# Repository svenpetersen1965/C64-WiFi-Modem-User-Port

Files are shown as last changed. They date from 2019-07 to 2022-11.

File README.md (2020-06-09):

# C64-WiFi-Modem-User-Port
A NodeMCU (ESP8266) based WiFi modem for the C64's user port
This is a Wifi-Modem for the Commodore C64 Uperport, which is based on the ESP8266 (NodeMCU v3). It contains level shifters to 
translate between the NodeMCU 3.3V level and the User Port 5V level. This prevents stressing the User Port due to a level mismatch.

Further on, status LEDs and (in Rev. 1) a Reset switch is contained.

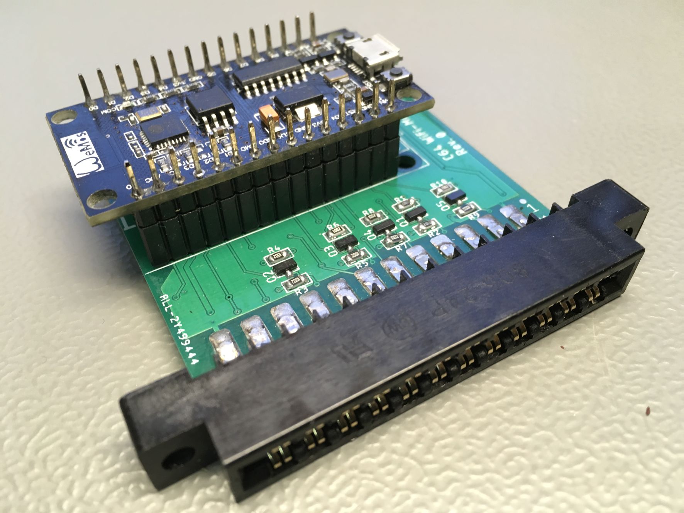
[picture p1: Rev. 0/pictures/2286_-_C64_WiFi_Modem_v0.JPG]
C64 Wifi modem


About the NodeMCU v3: There is a version, which is wider. The version that work is WeMOS NodeMCU v3, which is about 25.4mm wide. You can compare it to this picture, please. The right one has the labeling of the pins parallel to the edge of the PCB. 

The wiring follows the instruction on https://1200baud.wordpress.com/2017/03/04/build-your-own-9600-baud-c64-wifi-modem-for-20/ 

The firmware, required for the NodeMCU, can be obtained from the same website. Please follow the setup procedure described there.

Now, the STL files for a 3D printed case are available for this project.

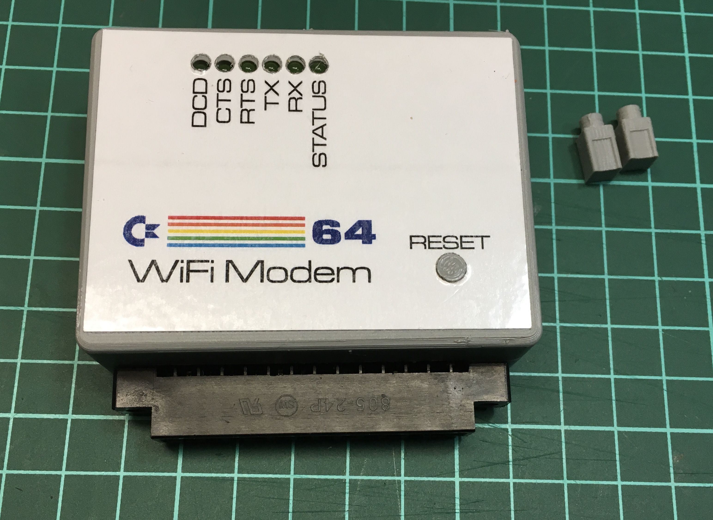
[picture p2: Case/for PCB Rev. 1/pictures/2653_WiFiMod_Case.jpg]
C64 Wifi modem (case)


There are three types of reset switch plungers for some common tact switch heights (4.3mm, 5mm and 7mm).

Rev. 1 works well, but only accepts the (smaller) WeMos NodeMCU v3 (approximately 48mx25mm). There is a bigger version available from the common sales platforms, which are bigger: 31mm x 57mm and don't fit the footprint of Rev. 1. This led to Rev. 2, which is now tested and working completely. 

Both sizes of the NodeMCU

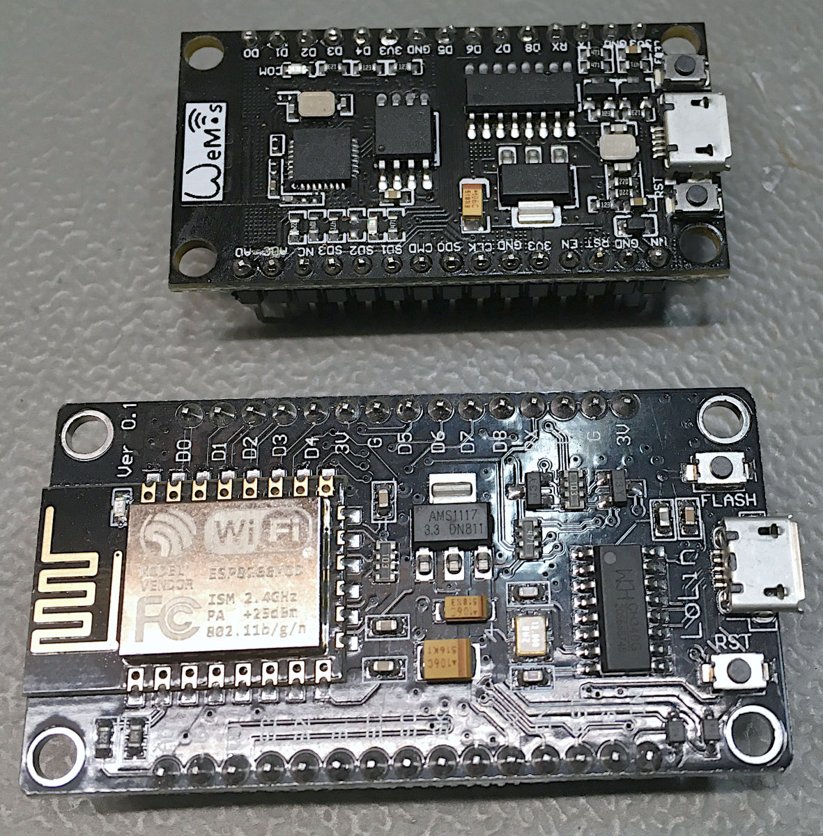
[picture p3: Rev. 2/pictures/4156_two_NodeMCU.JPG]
both sizes of NodeMCU


WiFi Modem Rev. 2 in case

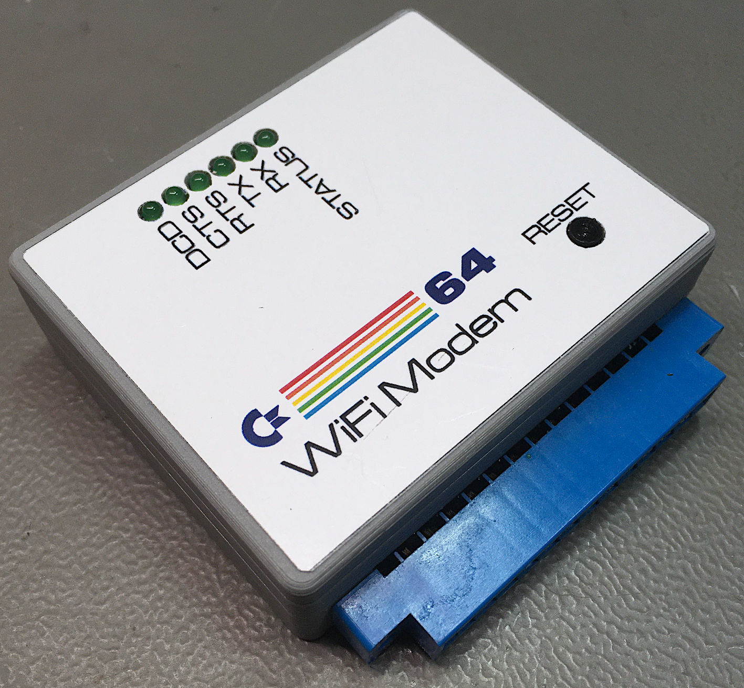
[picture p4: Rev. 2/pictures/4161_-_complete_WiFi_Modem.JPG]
C64 Wifi modem (case)


A nice blog about this project can be found here: <a href="https://medium.com/@gozdnijezek/c64-wifi-modem-user-port-by-sven-petersen-commodore-wifi-modem-21ab0eed411d">GozdniJezek: C64-WiFi-Modem-User-Port by Sven Petersen (Commodore WiFi modem)</a>

# Recommended Screws
For the case, I have used 2.9mm x 9.5mm (self taping) screws for sheet metal (C 2,9x9,5H, DIN 7981). 

# Calculation of the Component prices
The prices of the components was summed up. The total costs without the 3D printed case and any shipping fees is 16.19€ (May 2020). This might differ, depending on the source of the parts the Node MCU v3 can be obtained from non-domestic sources for less.

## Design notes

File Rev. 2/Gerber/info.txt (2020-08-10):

      
       Board: C64_Wifi_UserP
       Rev.:  2
  
       Files:
       ======
  
       All Gerber files are generated in extended gerber format (RS274X)
       *.TOP        : Film top copper
       *.BOT        :  -"- bottom copper
       *.STC        :  -"- top soldermask 
       *.STS        :  -"- bottom soldermask
       *.CRC        :  -"- cream top
       *.PLC        :  -"- silk screen top
       *.PLS        :  -"- silk screen bottom
       *.DK         : Drills plated Through (Excellon)
       *.NDK        : Drills not plated Through (Excellon)
       *.OUT        : Board outline
       
       Board Size:
       ===========
       Length     :   59.0 mm
       Width      :   53.3 mm
       Thickness  :   1.6 mm
       Material   :   FR 4
       Copper     :   35 um
       Surface    :   HASL
       
       Remarks:
       ========
       Width:    >=6mil
       Distance: >=6mil
       Drill:    >=0.35mm

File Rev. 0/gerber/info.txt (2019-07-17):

      
       Board: C64_Wifi_UserP
       Rev.:  0
  
       Files:
       ======
  
       All Gerber files are generated in extended gerber format (RS274X)
       *.TOP        : Film top copper
       *.BOT        :  -"- bottom copper
       *.STC        :  -"- top soldermask 
       *.STS        :  -"- bottom soldermask
       *.PLC        :  -"- silk screen top
       *.DK         : Drills plated Through (Excellon)
       *.NDK        : Drills not plated Through (Excellon)
       *.OUT        : Board outline

       Board Size:
       ===========
       Length     :   54.0 mm
       Width      :   53.3 mm
       Thickness  :   1.6 mm
       Material   :   FR 4
       Copper     :   35 um
       Surface    :   HASL
       
       Remarks:
       ========

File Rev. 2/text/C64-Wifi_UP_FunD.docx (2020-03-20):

C64 WiFi-Modem for User Port Rev. 2

Functional Description

J1 is connecting to the C64 user port. The logic levels are TTL (5V)-levels. The NodeMCU v3 (M1) contains all functionality, WiFi included. Its signal level is 3.3V, so level shifters are required. Those are implemented in the MOSFETs (Q1 – Q5).

The modem signals are active low. The inverters (IC1) are used to drive LEDs. The RxD and TxD lines might toggle often. To obtain a good LED brightness, the output of the inverters IC1D and IC1E are buffered in a capacitor, which is charged via a diode and discharged via the base resistor and the base of a transistor, which is then driving an LED.

The last LED (LD6) is driven by the signal EXLED from the NodeMCU. It serves as a status LED for the NodeMCU software. According to the comments in the software, a LOW on this output should switch the Status-LED on, thus the inverter IC1F is required.

J2 is a spare SPI bus connection. The functionality is not implemented in the software, the pin header may stay not populated.

SW1 serves as a RESET switch for the C64. It is a standard 6mm tact switch.

A LOW level on the C64’s signal pulls the NodeMCU’s LOW via the Schottky diode D3. This way, the NodeMCU is reset together with the C64.

C64-Wifi_UP_FunD.docx 05.02.2020 11:49 Drafted by Sven Petersen Page 2 of 2 Doc.-No.: 000-6-00-00

C64-Wifi_UP_FunD.docx 05.02.2020 11:49 Drafted by Sven Petersen Page 1 of 1 Doc.-No.: 120-6-01-02

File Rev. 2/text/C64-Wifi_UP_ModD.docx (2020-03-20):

C64 WiFi-Modem for User Port Rev. 2

Module Description

This board is a WiFi modem for the User Port of the Commodore C64. It is based on the project “Build your own 9600 Baud C64 WiFi Modem For $10” of “1200BAUD” (https://1200baud.wordpress.com/2017/03/04/build-your-own-9600-baud-c64-wifi-modem-for-20/).

The WiFi functionality is implemented in the NODEMCU V3 development board/module, which contains an Espressive ESP8266, a WiFi and RISC processor. This module can be programmed with free software via a micro USB cable.

The board contains status and activity LEDs and connects to the User Port of the Commodore C64.

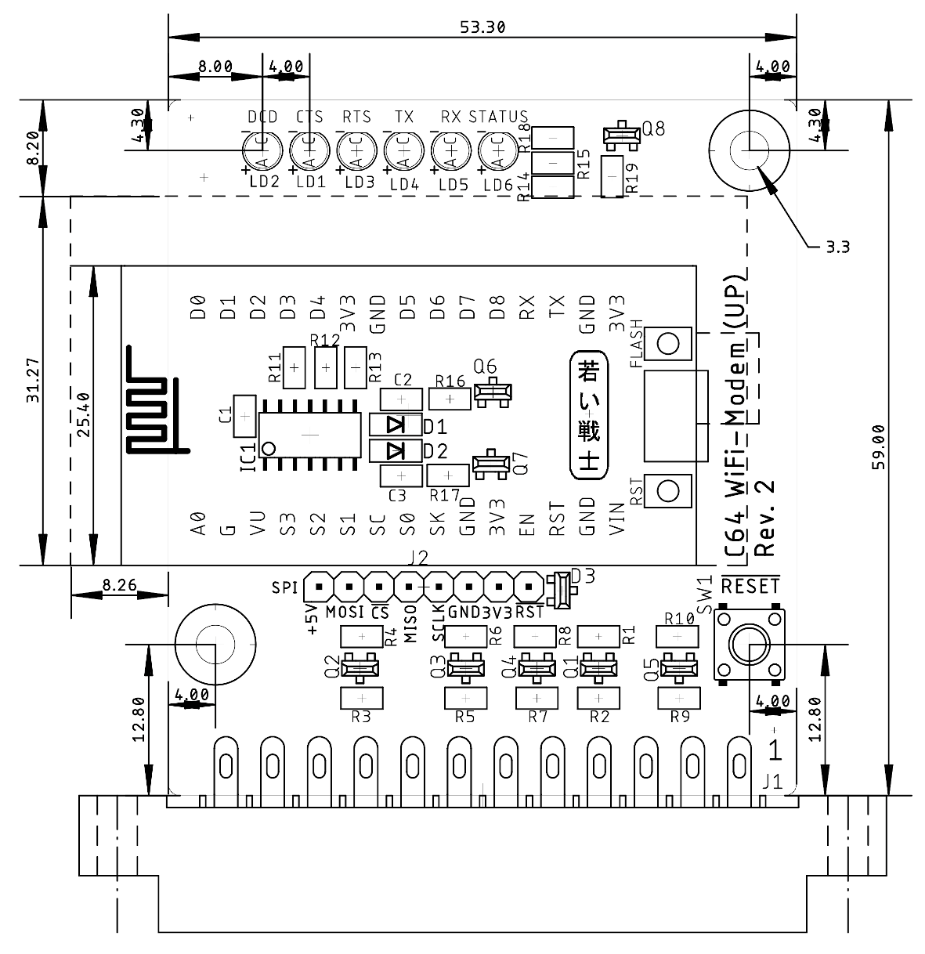
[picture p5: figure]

Figure 1: Dimensions of the WiFi modem board

For the NodeMCU V3 programming and the required C64 software, refer to the article mentioned before.

The board contains level shifters, that translate between the NodeMCU 3.3V level and the User Port 5V level. According to the data sheet, the ESP8266 is not 5V-level tolerant. Its protection diodes might limit the HIGH level to below 4V. Without the level shifters, the User Port/6526 CIA might be stressed by the HIGH level being pulled to this level.


Figure 2: The narrow and the wide NodeMCU

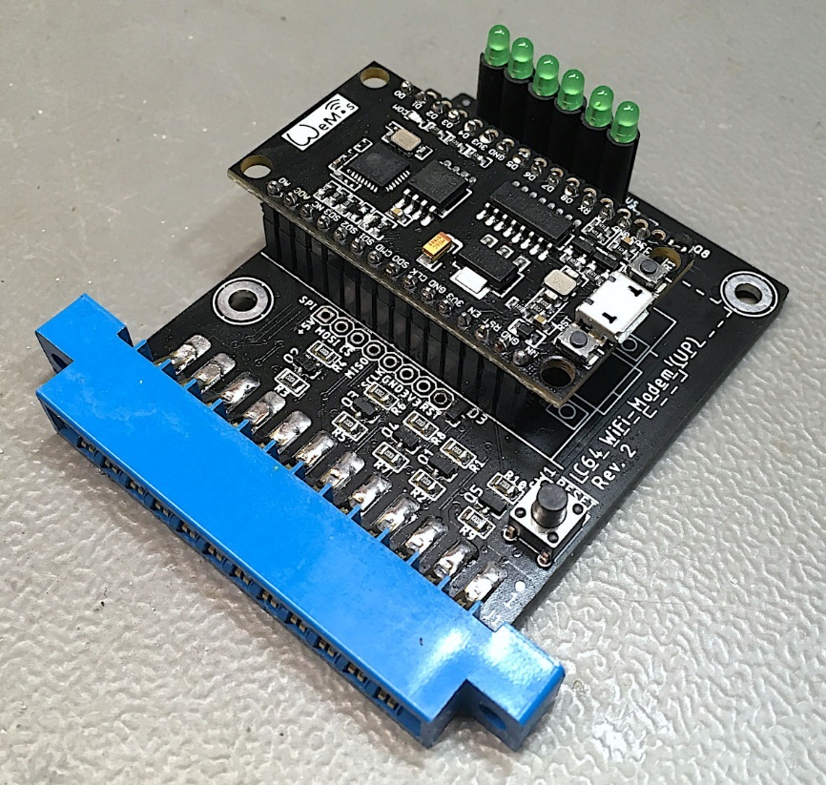
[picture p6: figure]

Figure 3: WiFi Modem with narrow NodeMCU v3

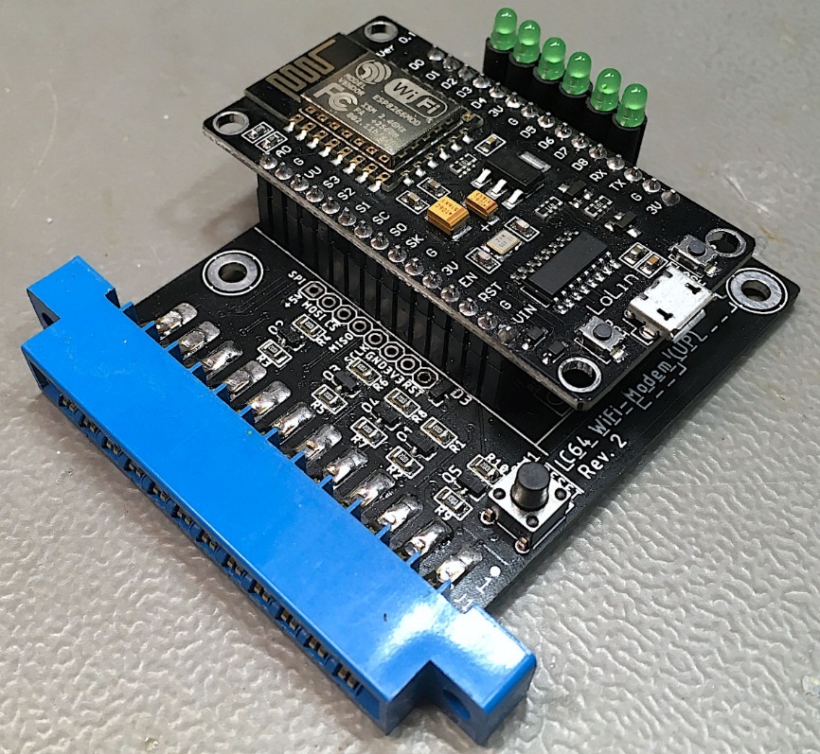
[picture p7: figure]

Figure 4: WiFi modem with the wide NodeMCU

# Logic connections

3.3V level | | | 5V level
Pin | NodeMCU V3 | Signal | User Port | Pin
29 | GPIO5 (D1) | RTS | PB1 | D
28 | GPIO4 (D2) | CTS | PB6 | K
26 | GPIO2 (D4) | DCD | PB4 | H
22 | GPIO12 (D6) | Status-LED | - | -
19 | RXD0 (RX) | RXD | PA2, SP1 | M, 5
18 | TXD0 (TX) | TXD | /FLAG2, PB0, SP2 | B, C, 7
- | - | | PB7, CNT2 | L, 6

# Connectors

## User Port

2 x 12 edge connector, pitch 3.96mm

Pin | Signal | Pin | Signal
1 | GND | A | GBD
2 | +5V | B, C | TXD
3 | | D | RTS
5 | RXD | H | DCD
6 | CNT2 | K | CTS
7 | TXD | L | CNT2
12 | GND | M | RXD
| | N | GND

## SPI (spare)

8p. pin header, pitch 2.54mm. The function of the SPI-Bus is not implemented in the NodeMCU software. The signals have a 3.3V level. 3.3V, 5V and GND are connected to this pin header.

Pin | Signal
1 | +5V
2 | MOSI
3
4 | MISO
5 | SCLK
6 | GND
7 | +3.3V
8 | (Reset Signal NodeMCU)

# Revision History

## Rev. 0

Prototype, functional. Labeling of the LEDs was not perfect, the Status LED was inverted.

## Rev. 0 → Rev. 1

- Board Revision
- LEDs changed to 3mm standard LEDs
- The “WiFi” LED is now named “Status” and it is inverted
- The Labeling from RX and TX was swapped, since before it was labeled from the perspective of the NodeMCU
- Positions of LEDs have moved
- A pin header for a spare SPI-Bus connection is added
- Two mounting holes for a not yet designed enclosure are added
- A -Button is added
- The C64 Reset affects the NodeMCU

## Rev. 1 → Rev. 2

- Board Revision
- The original WeMos NodeMCU footprint and the wider footprint of other vendors both fit the PCB
- The case Rev. 2 is required

C64-Wifi_UP_ModD.docx 20.03.2020 19:02 Drafted by Sven Petersen Page 2 of 2 Doc.-No.: 120-6-01-02

C64-Wifi_UP_ModD.docx 20.03.2020 19:02 Drafted by Sven Petersen Page 1 of 1 Doc.-No.: 120-6-01-01

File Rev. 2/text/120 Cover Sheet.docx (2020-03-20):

Project Documentation

C64 WiFi-Modem for User Port

Project number: 120

Revision: 2

Date: 05.02.2020

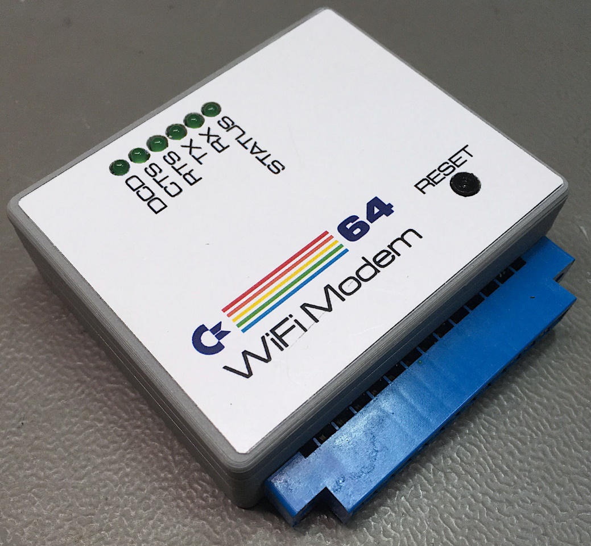
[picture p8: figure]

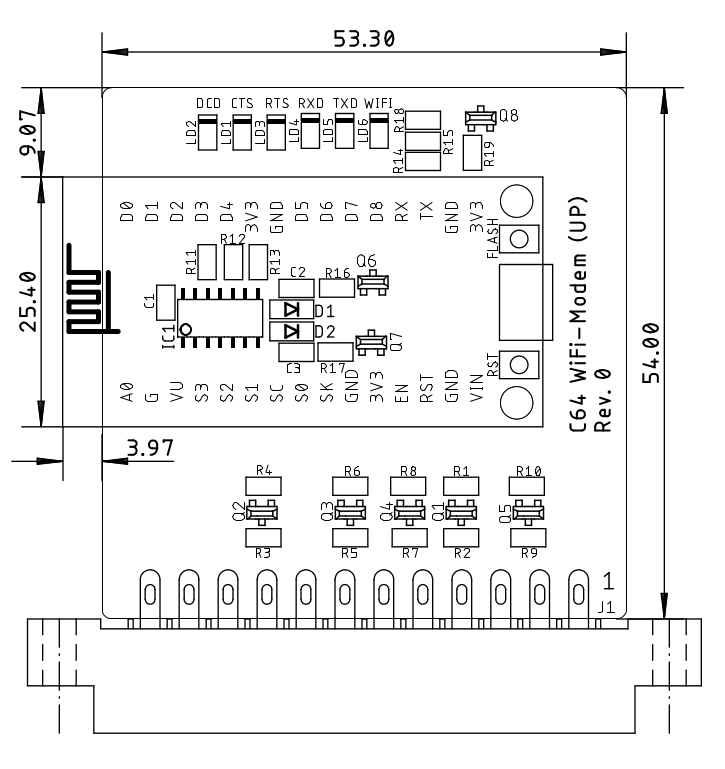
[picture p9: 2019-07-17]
Rev. 0/pictures/C64_WiFi_UP.png

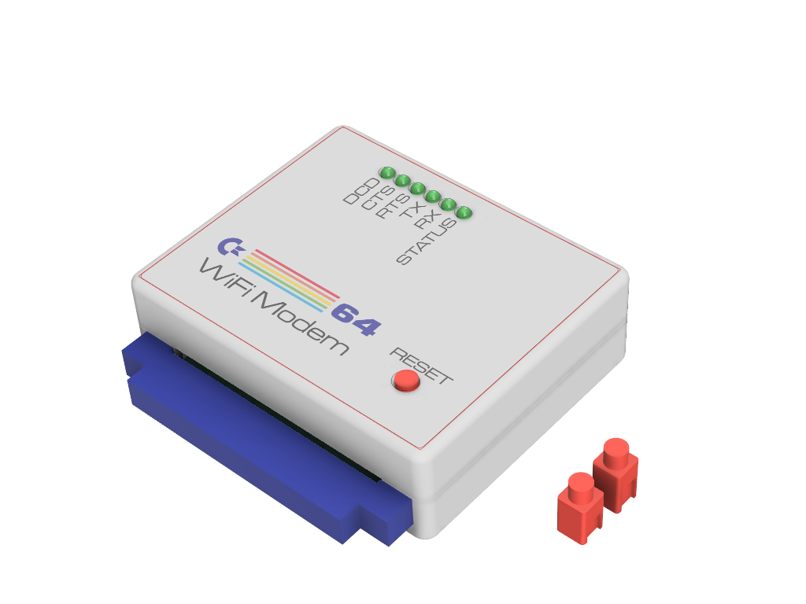
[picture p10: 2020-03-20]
Case/for PCB Rev. 2/pictures/C64-WiFi_UP_PCB2 v7.png

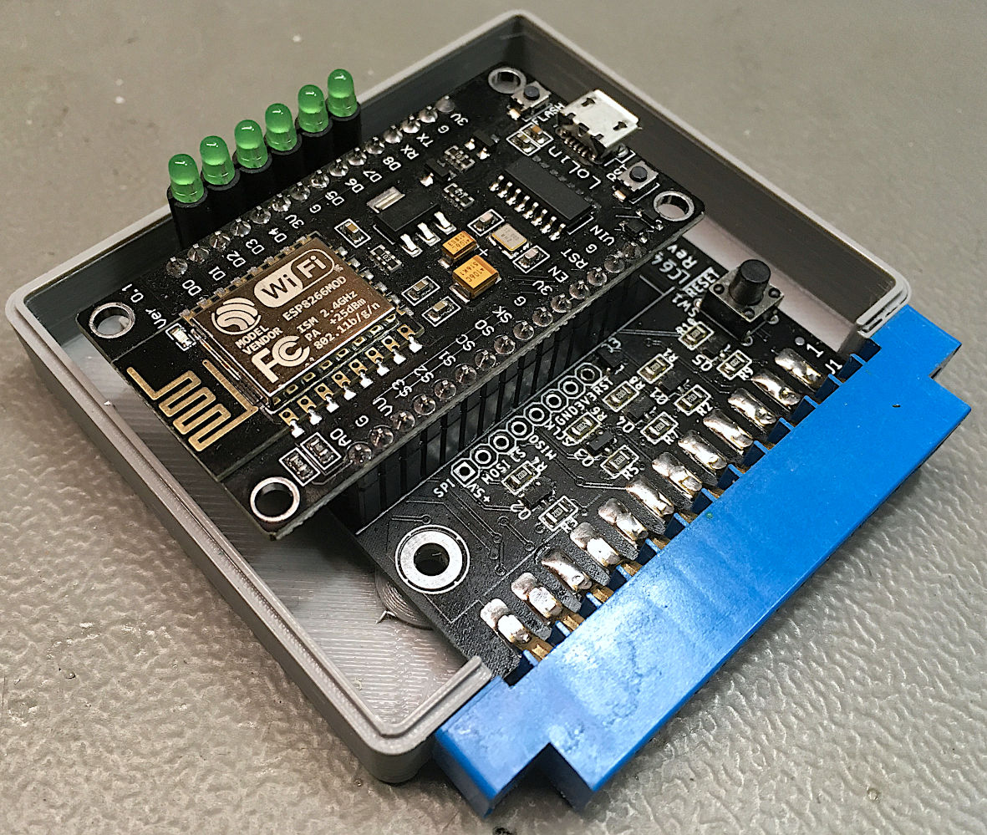
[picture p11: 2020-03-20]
Rev. 2/pictures/4159_-_in_bottom_shell.JPG

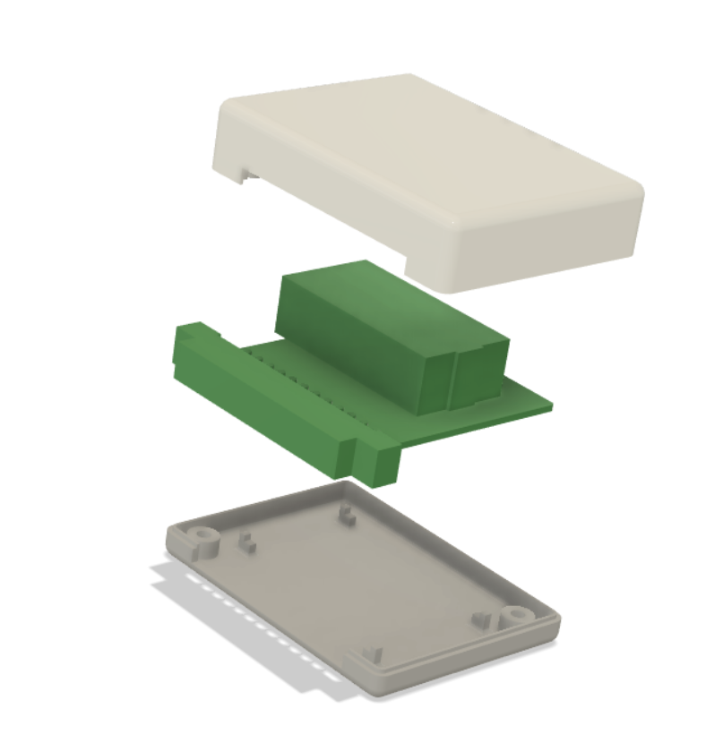
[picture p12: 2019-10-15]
Case/for PCB Rev. 0/pictures/C64-Wifi_UP_PCB0_explosion.png

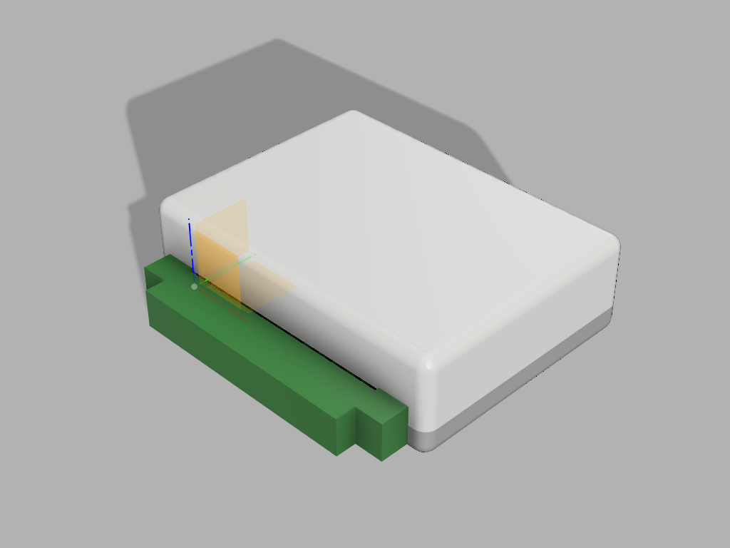
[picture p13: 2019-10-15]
Case/for PCB Rev. 0/pictures/C64-Wifi_UP_PCB0 v5.png

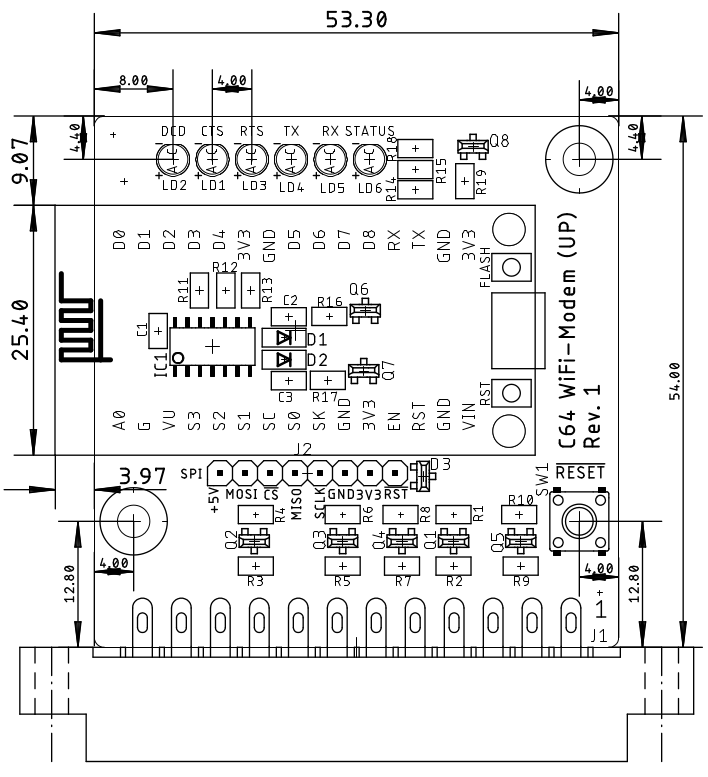
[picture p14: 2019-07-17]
Rev. 1/pictures/C64_WiFi_UP.png

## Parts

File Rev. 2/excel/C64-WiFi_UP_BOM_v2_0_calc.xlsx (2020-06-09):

C64 WiFi-Modem for User Port Rev. 2
Bill of Material Rev. 2.0
Pos. | Qty | Value | €/each | € | Comment
1 | 1 | 120-2-01-01 | 1.00 € | 1.00 € | 2 layer, Cu 35µ, HASL, 54.0 x 53.3, 1.6mm FR4
2 | 6 | 3mm/gn | 0.07 € | 0.42 € | Standard 3mm green LEDs
3 | 3 | 100n | 0.05 € | 0.15 € | ceramic cap, 0805, 25V or better
4 | 13 | 10k | 0.03 € | 0.39 € | chip resistor, 0805, 5% or better
5 | 6 | 330R | 0.03 € | 0.18 € | chip resistor, 0805, 5% or better
6 | 1 | 74HC14D | 0.20 € | 0.20 € | ST micro, NXP, TI etc. e.g. Reichelt SMD HC 14
7 | 3 | BC846B | 0.02 € | 0.06 € | SMD NPN transistor, e.g. Reichelt BC 846B NXP
8 | 5 | BSS138 | 0.04 € | 0.20 € | SMD MOSFET, e.g. Reichelt BSS 138 SMD
9 | 1 | 2x12, 3.96mm pitch | 3.00 € | 3.00 € | edge connector for C64 user port, ebay or online shops
10 | 2 | LL4148 | 0.02 € | 0.04 € | diode SMD, e.g. Reichelt LL4148
11 | 1 | NodeMCU V3 | 8.40 € | 8.40 € | e.g. WeMOS NodeMCU v3. ebay or online shops or Reichelt DEBO JT ESP8266, either the origial narror footprint or the 31.1mm wide footprint of other vendors.
12 | 2 | socket strip 15p. 2.54mm pitch | 0.99 € | 1.98 € | e.g. MPE Garry 115-1-015, Reichelt MPE 115-1-015
13 | 1 | 8p, 2.54mm pin header | 0.00 € | 0.00 € | not populated
14 | 1 | BAT54 | 0.02 € | 0.02 € | schottky diode
15 | 1 | JTP-1130 | 0.15 € | 0.15 € | Namea Electronics. Or standard 6x6mm tact switch
16 |  |  | Total | 16.19 €

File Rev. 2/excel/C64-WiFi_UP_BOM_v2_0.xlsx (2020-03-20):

C64 WiFi-Modem for User Port Rev. 2
Bill of Material Rev. 2.0
Pos. | Qty | Value | Footprint | Ref.-No. | Comment
1 | 1 | 120-2-01-01 | 2 Layer | PCB Rev. 1 | 2 layer, Cu 35µ, HASL, 54.0 x 53.3, 1.6mm FR4
2 | 6 | 3mm/gn | 3mm LED | LD1, LD2, LD3, LD4, LD5, LD6 | Standard 3mm green LEDs
3 | 3 | 100n | 0805 | C1, C2, C3 | ceramic cap, 0805, 25V or better
4 | 13 | 10k | 0805 | R1, R2, R3, R4, R5, R6, R7, R8, R9, R10, R16, R17, R19 | chip resistor, 0805, 5% or better
5 | 6 | 330R | 0805 | R11, R12, R13, R14, R15, R18 | chip resistor, 0805, 5% or better
6 | 1 | 74HC14D | SO-14 | IC1 | ST micro, NXP, TI etc. e.g. Reichelt SMD HC 14
7 | 3 | BC846B | SOT23 | Q6, Q7, Q8 | SMD NPN transistor, e.g. Reichelt BC 846B NXP
8 | 5 | BSS138 | SOT23 | Q1, Q2, Q3, Q4, Q5 | SMD MOSFET, e.g. Reichelt BSS 138 SMD
9 | 1 | 2x12, 3.96mm pitch | USERPORT | J1 | edge connector for C64 user port, ebay or online shops
10 | 2 | LL4148 | SOD80C | D1, D2 | diode SMD, e.g. Reichelt LL4148
11 | 1 | NodeMCU V3 | NODEMCUV3 | M1 | e.g. WeMOS NodeMCU v3. ebay or online shops or Reichelt DEBO JT ESP8266, either the origial narror footprint or the 31.1mm wide footprint of other vendors.
12 | 2 | socket strip 15p. 2.54mm pitch |  | (M1) | e.g. MPE Garry 115-1-015, Reichelt MPE 115-1-015
13 | 1 | 8p, 2.54mm pin header |  | J2 | not populated
14 | 1 | BAT54 | SOT23 | D3 | schottky diode
15 | 1 | JTP-1130 | 6mm tact switch | SW1 | Namea Electronics. Or standard 6x6mm tact switch
 |  | Rev. 0 -> Rev. 1
Pos. | 1 | Board Revision
Pos. | 2 | changed to 3mm led
Pos. | 13 | new
Pos. | 14 | new
Pos. | 15 | new
 |  | Rev. 1 -> 2
Pos. | 1 | Board Revision

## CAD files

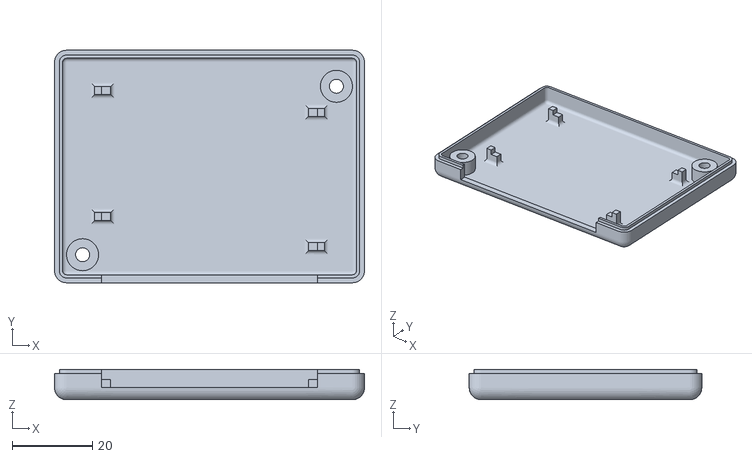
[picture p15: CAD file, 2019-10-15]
Case/for PCB Rev. 0/stl/bottom shell.stl
77.3 x 58.0 x 7.60

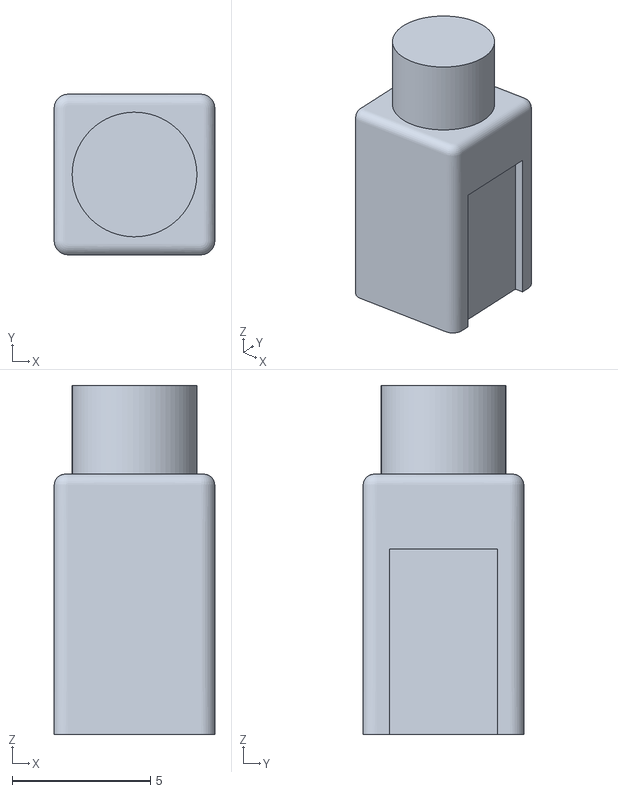
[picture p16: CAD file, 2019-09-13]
Case/for PCB Rev. 1/STL/Plunger (4.3mm).stl
5.80 x 5.80 x 12.6

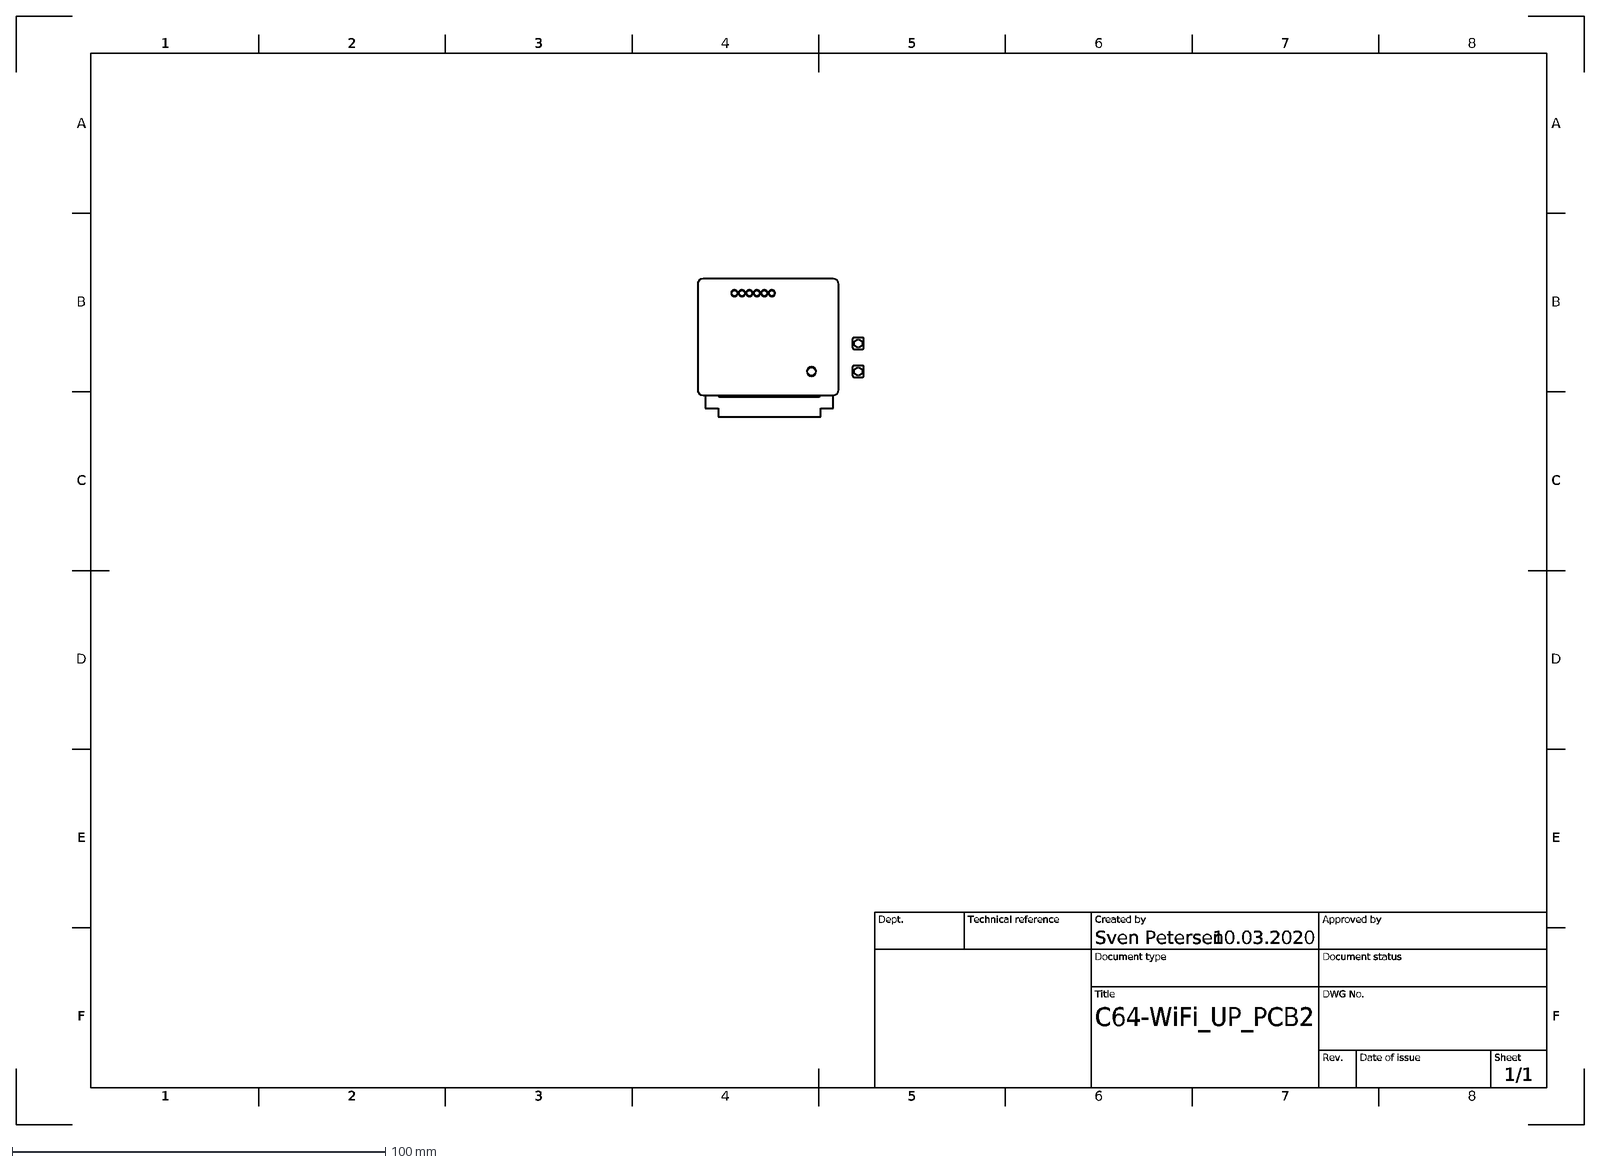
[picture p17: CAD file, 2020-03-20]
Case/for PCB Rev. 2/label/dxf/Untitled Sheet1.dxf
1
A
2
3
4
5
6
7
8
B
C
D
E
F
10.03.2020
1/1
C64-WiFi_UP_PCB2
Sven Petersen
Dept.
Technical reference
Created by
Approved by
Document type
Document status
Title
DWG No.
Rev.
Date of issue
Sheet

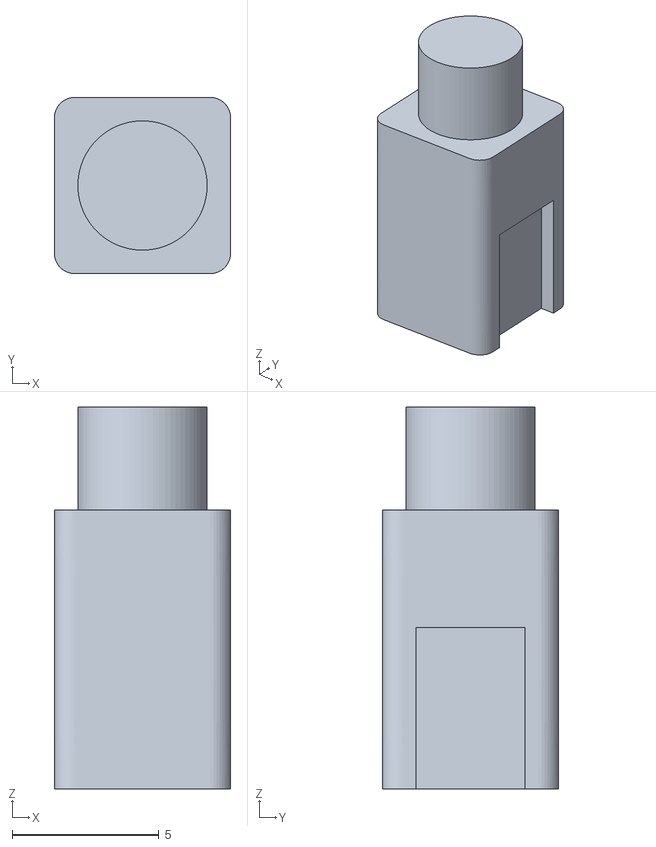
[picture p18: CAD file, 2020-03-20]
Case/for PCB Rev. 2/stl/plunger_4mm.stl
6.00 x 6.00 x 13.0

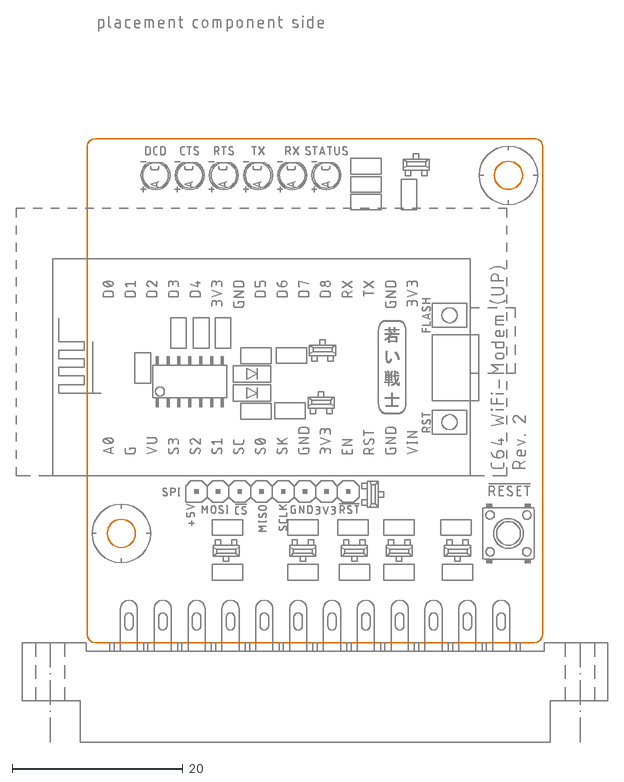
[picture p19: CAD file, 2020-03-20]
Rev. 2/dxf/C64-Wifi_UserP.dxf
69.2 x 84.9

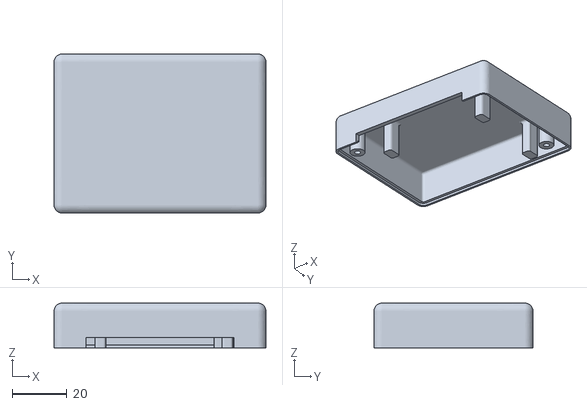
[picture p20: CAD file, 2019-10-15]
Case/for PCB Rev. 0/stl/Top shell.stl
77.3 x 58.0 x 16.4

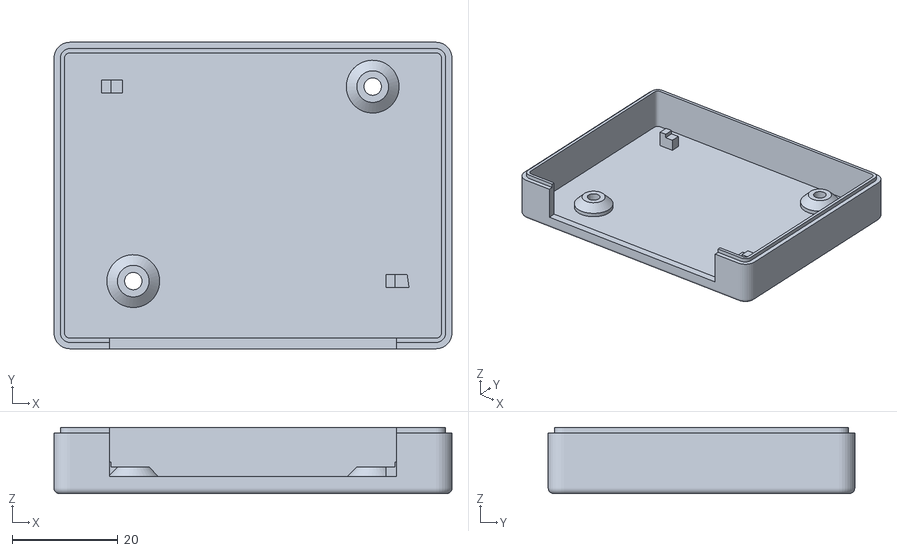
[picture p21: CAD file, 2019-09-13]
Case/for PCB Rev. 1/STL/bottom shell.stl
75.3 x 58.0 x 12.5

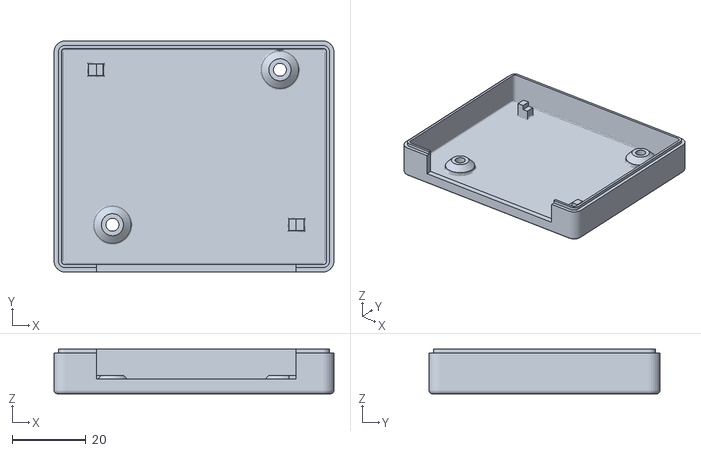
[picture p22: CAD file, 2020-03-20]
Case/for PCB Rev. 2/stl/C64_Wifi2_bottom.stl
75.7 x 62.5 x 12.1

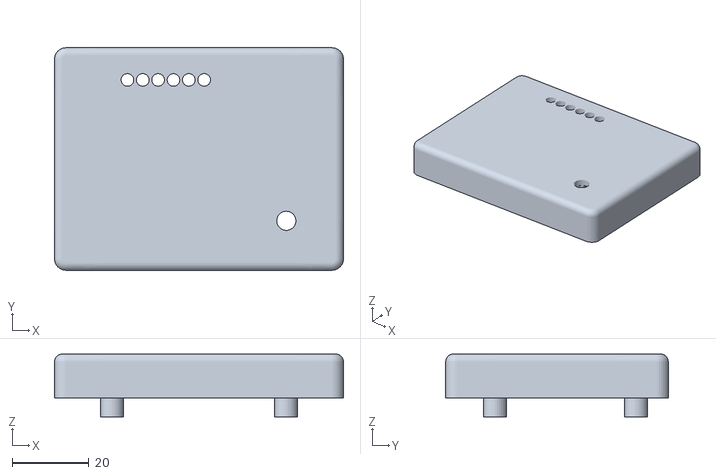
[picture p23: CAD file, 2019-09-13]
Case/for PCB Rev. 1/STL/Top shell.stl
75.3 x 58.0 x 16.4

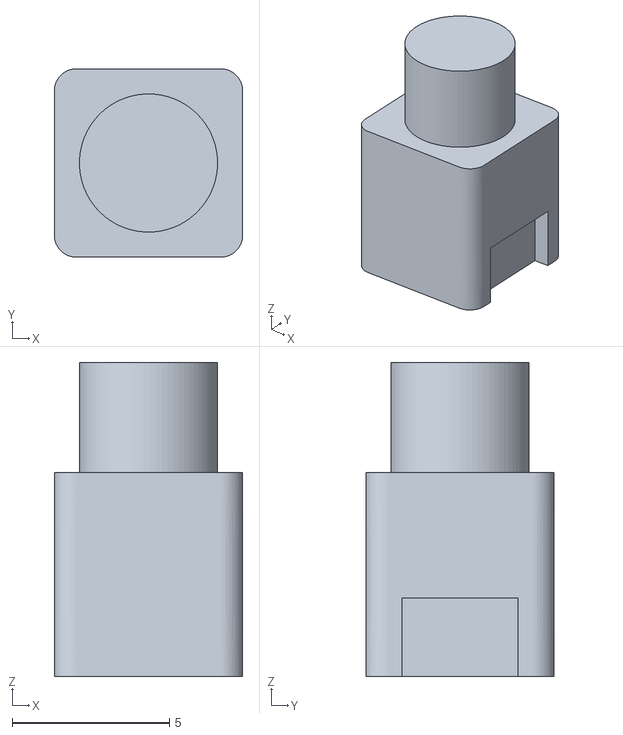
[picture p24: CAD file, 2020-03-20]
Case/for PCB Rev. 2/stl/plunger_7mm.stl
6.00 x 6.00 x 10.0

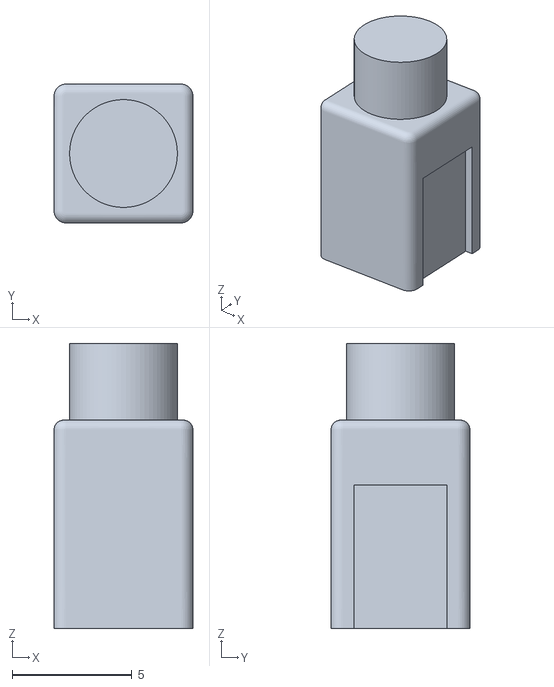
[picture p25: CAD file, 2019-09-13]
Case/for PCB Rev. 1/STL/Plunger (5mm).stl
5.80 x 5.80 x 11.9

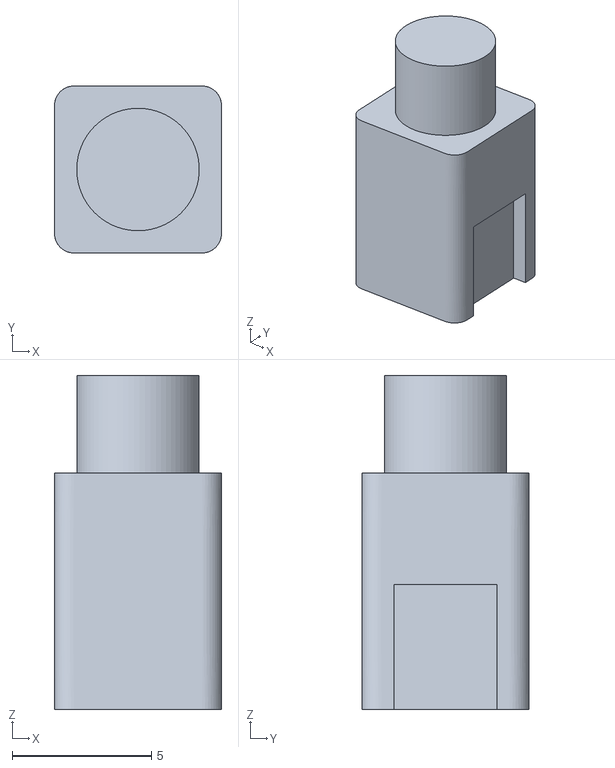
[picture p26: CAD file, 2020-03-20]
Case/for PCB Rev. 2/stl/plunger_5mm.stl
6.00 x 6.00 x 12.0

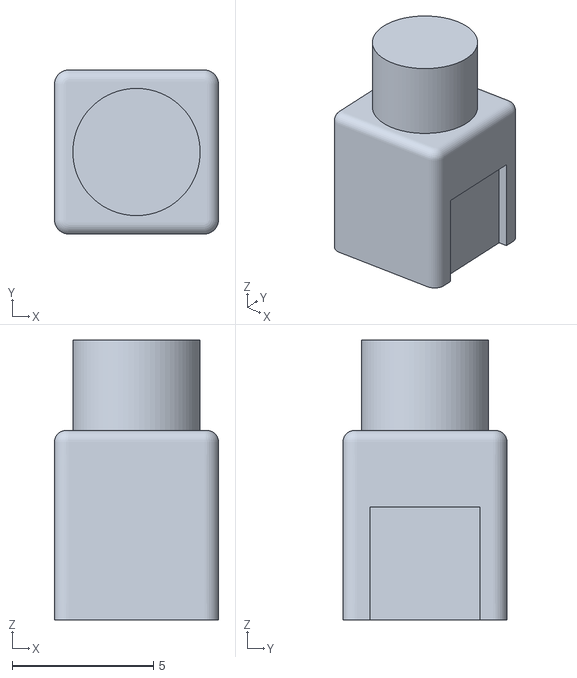
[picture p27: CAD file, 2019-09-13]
Case/for PCB Rev. 1/STL/Plunger (7mm).stl
5.80 x 5.80 x 9.90

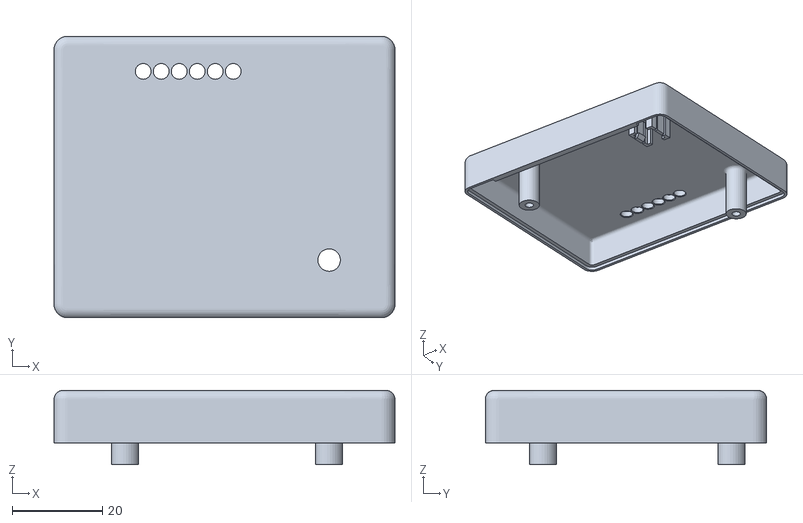
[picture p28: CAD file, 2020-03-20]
Case/for PCB Rev. 2/stl/C64_WiFi2_Top.stl
75.7 x 62.5 x 16.5

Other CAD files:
Case/for PCB Rev. 0/fusion 360/C64-Wifi_UP_PCB0 v6.f3d
Case/for PCB Rev. 1/Fusion 360/C64-Wifi_UserP v34.f3d
Case/for PCB Rev. 2/Fusion 360/C64-WiFi_UP_PCB2 v9.f3d

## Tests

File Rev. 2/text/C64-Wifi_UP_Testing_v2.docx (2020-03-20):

C64 WIFI Modem (User Port) Rev. 2

Testing v2

# Setup

The C64 WiFi Modem (Rev. 1) is driven by a C64 (Mainboard: ASSY250469 with ARMSID), which also connects to an Ultimate II+.

# Current consumption

The current is measured with a Fluke 89 IV multimeter, which is connected between the power supply and the Power jack of the C64.

First the maximum current of the C64 setup mentioned before is determined without the DUT being connected to the user port. CCGMS 2017 v6 was loaded from the Ultimate II+.

The measured result IMAX is 998.7mA.

In the next step, the DUT was connected and the measurement was repeated. This time, the result is 1095.5mA.

The current consumption of the Modem board might vary depending on the operations/state. It can eb assumed, that is it approximately 100mA.

# Connection Test

With the CCGMS software, the Modem was set up, three different WiFi connections were established:

- An iPad Pro acting as an access point
- A WAP (wireless access point)
- A Router

The connections to the WiFi networks could be established, repeatedly. The WAP did not connect anymore after a few days. Since the WAP was far away and all other connections continued working, it was assumed, that either the settings or the distance of the WAP were causing the problem.

After setting up the dialer with several BBS connections and Port numbers, the WiFi-Modem and CCGMS software could connect to those BBSes and exchange data and hold the connection in a stable behavior.

# Conclusion

The functionality of Rev. 0 is given, the labeling of the LEDs needs to be changed. The Status LED needs to be inverted. Refer to document 120-6-03-00: Testing Rev. 0.

Rev. 1 was built and tested. The LEDs cab be viewed properly, their behavior is ok. The reset button resets both, the C64 and the modem. The modem does not reset the C64. The designed 3D printed case (for PCB Rev. 1) fits well. The modem connects to WiFi and is able to dial in a variety of BBSes.

Rev. 2 was built and tested. The designed 3D printed case (for PCB Rev. 2) fits well. The tests were conducted with both, the narrow NodeMCU and the wide NodeMCU. The modem connects to WiFi and is able to dial in a variety of BBSes.

C64-Wifi_UP_Testing_v2.docx 20.03.2020 19:12 Drafted by Sven Petersen Page 2 of 2 Doc.-No.: 120-6-03-02

C64-Wifi_UP_Testing_v2.docx 20.03.2020 19:12 Drafted by Sven Petersen Page 1 of 1 Doc.-No.: 120-6-03-01.1

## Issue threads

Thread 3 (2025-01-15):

Do we need a specific height female pin header?

kennyevo, 2025-01-15:
I’ve assembled a rev2 board with the exact same nodemcu that’s in the readme, but the rev2 top case doesn’t sit on the pcb, the nodemcu sits too high.
What height should the socket headers be?

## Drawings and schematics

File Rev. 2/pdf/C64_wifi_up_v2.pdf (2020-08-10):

# Project Documentation

## C64 WiFi-Modem for User Port

## Project number: 120

## Revision: 2

## Date: 05.02.2020

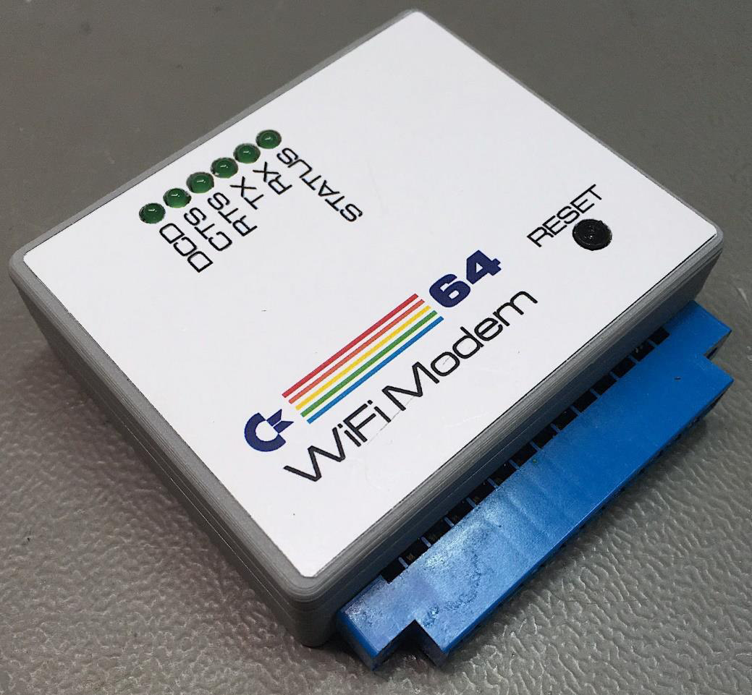
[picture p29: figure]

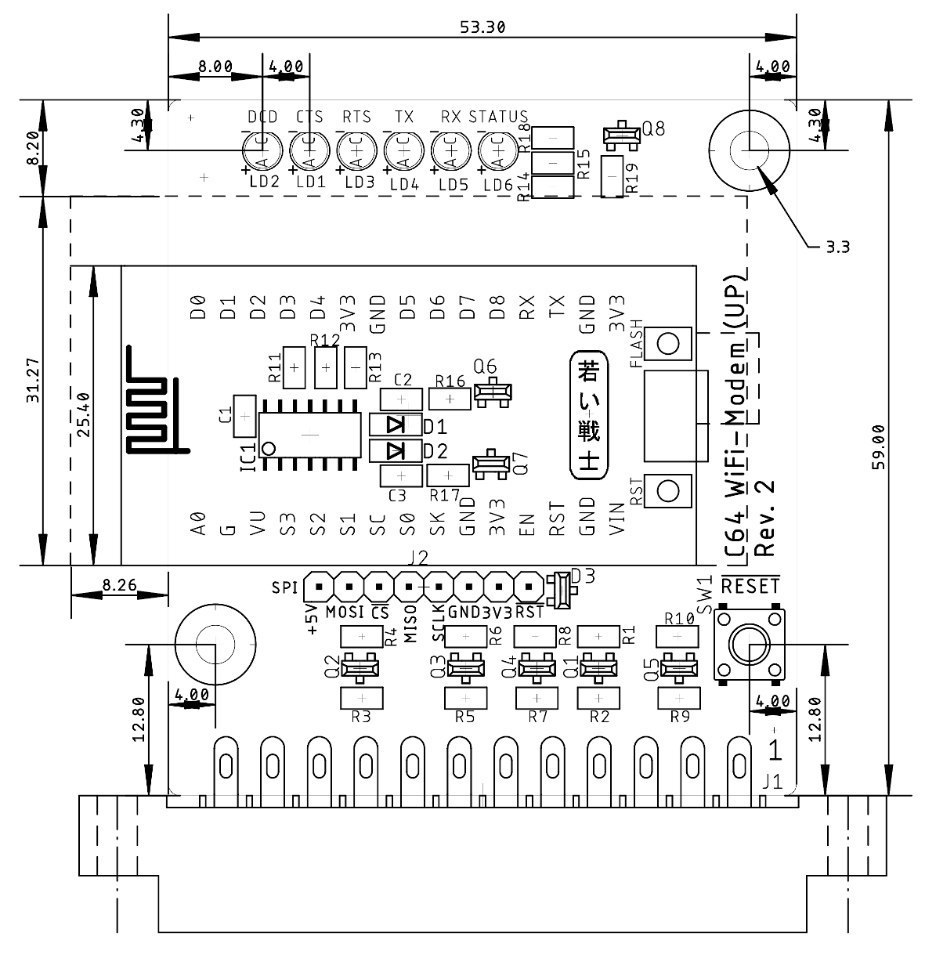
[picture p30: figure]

C64-Wifi_UP_ModD.docx | | 20.03.2020 19:02
Drafted by Sven Petersen | Page 1 of 4 | Doc.-No.: 120-6-01-02

### C64 WiFi-Modem for User Port Rev. 2

### Module Description

This board is a WiFi modem for the User Port of the Commodore C64. It is based on the project “Build your own 9600 Baud C64 WiFi Modem For $10” of “1200BAUD” (https://1200baud.wordpress.com/2017/03/04/build-your-own-9600-baud-c64-wifi-modem-for-20/). (https://1200baud.wordpress.com/2017/03/04/build-your-own-9600-baud-c64-wifi-modem-for-20/)

The WiFi functionality is implemented in the NODEMCU V3 development board/module, which contains an Espressive ESP8266, a WiFi and RISC processor. This module can be programmed with free software via a micro USB cable.

The board contains status and activity LEDs and connects to the User Port of the Commodore C64.

Figure 1: Dimensions of the WiFi modem board

For the NodeMCU V3 programming and the required C64 software, refer to the article mentioned before.

The board contains level shifters, that translate between the NodeMCU 3.3V level and the User Port 5V level. According to the data sheet, the ESP8266 is not 5V-level tolerant. Its protection diodes might limit the HIGH level to below 4V. Without the level shifters, the User Port/6526 CIA might be stressed by the HIGH level being pulled to this level.

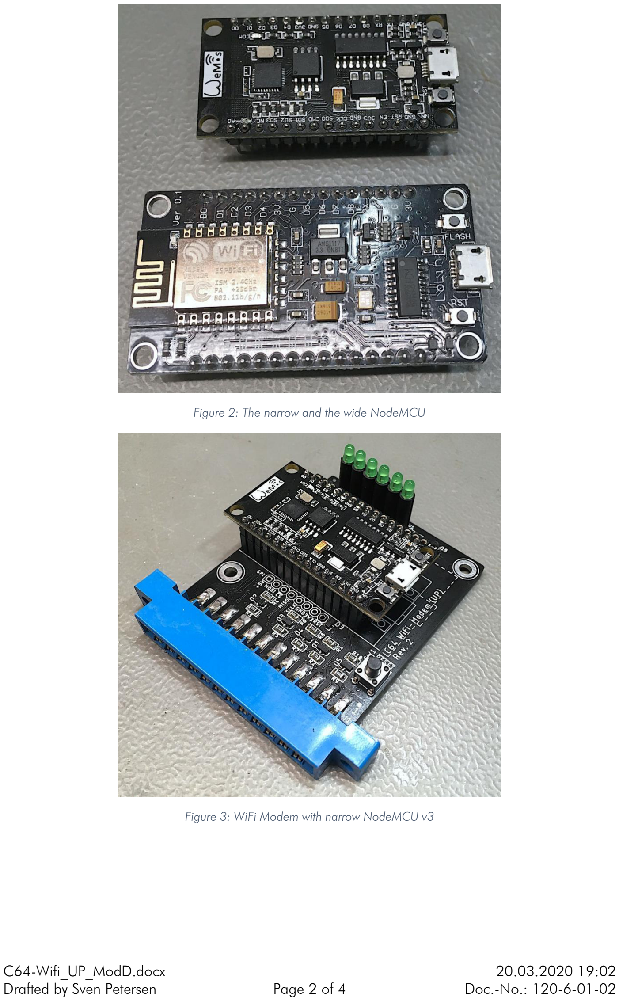
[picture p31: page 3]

C64-Wifi_UP_ModD.docx | | 20.03.2020 19:02
Drafted by Sven Petersen | Page 2 of 4 | Doc.-No.: 120-6-01-02

Figure 2: The narrow and the wide NodeMCU

Figure 3: WiFi Modem with narrow NodeMCU v3

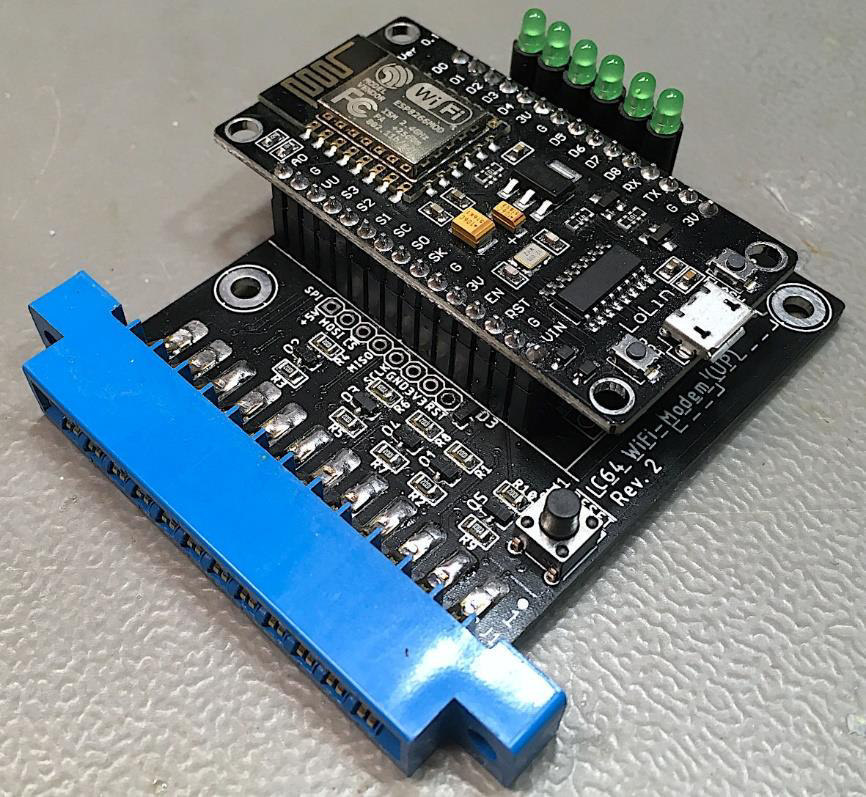
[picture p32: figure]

C64-Wifi_UP_ModD.docx | | 20.03.2020 19:02
Drafted by Sven Petersen | Page 3 of 4 | Doc.-No.: 120-6-01-02

Figure 4: WiFi modem with the wide NodeMCU

## Logic connections

| 3.3V level | | | 5V level
Pin | NodeMCU V3 | Signal | User Port | Pin
29 | GPIO5 (D1) | RTS | PB1 | D
28 | GPIO4 (D2) | CTS | PB6 | K
26 | GPIO2 (D4) | DCD | PB4 | H
22 | GPIO12 (D6) | Status-LED | - | -
19 | RXD0 (RX) | RXD | PA2, SP1 | M, 5
18 | TXD0 (TX) | TXD | /FLAG2, PB0, SP2 | B, C, 7
- | - | | PB7, CNT2 | L, 6

## Connectors

### User Port

### 2 x 12 edge connector, pitch 3.96mm

Pin Signal | Pin Signal
1 | GND | A | GBD
2 | +5V | B, C | TXD
3 | RESET | D | RTS
5 | RXD | H | DCD
6 | CNT2 | K | CTS
7 | TXD | L | CNT2
12 | GND | M | RXD
| | N GND

C64-Wifi_UP_ModD.docx | | 20.03.2020 19:02
Drafted by Sven Petersen | Page 4 of 4 | Doc.-No.: 120-6-01-02

### SPI (spare)

8p. pin header, pitch 2.54mm. The function of the SPI-Bus is not implemented in the NodeMCU software. The signals have a 3.3V level. 3.3V, 5V and GND are connected to this pin header.

Pin Signal
1 +5V
2 MOSI
3 CS

4 MISO
5 SCLK
6 GND
7 +3.3V
8 RST (Reset Signal NodeMCU)

## Revision History

### Rev. 0

Prototype, functional. Labeling of the LEDs was not perfect, the Status LED was inverted.

### Rev. 0 → Rev. 1

- Board Revision
- LEDs changed to 3mm standard LEDs

### - The “WiFi” LED is now named “Status” and it is inverted

- The Labeling from RX and TX was swapped, since before it was labeled from the perspective of the NodeMCU
- Positions of LEDs have moved
- A pin header for a spare SPI-Bus connection is added
- Two mounting holes for a not yet designed enclosure are added
- A RESET -Button is added
- The C64 Reset affects the NodeMCU

### Rev. 1 → Rev. 2

- Board Revision
- The original WeMos NodeMCU footprint and the wider footprint of other vendors both fit the PCB
- The case Rev. 2 is required

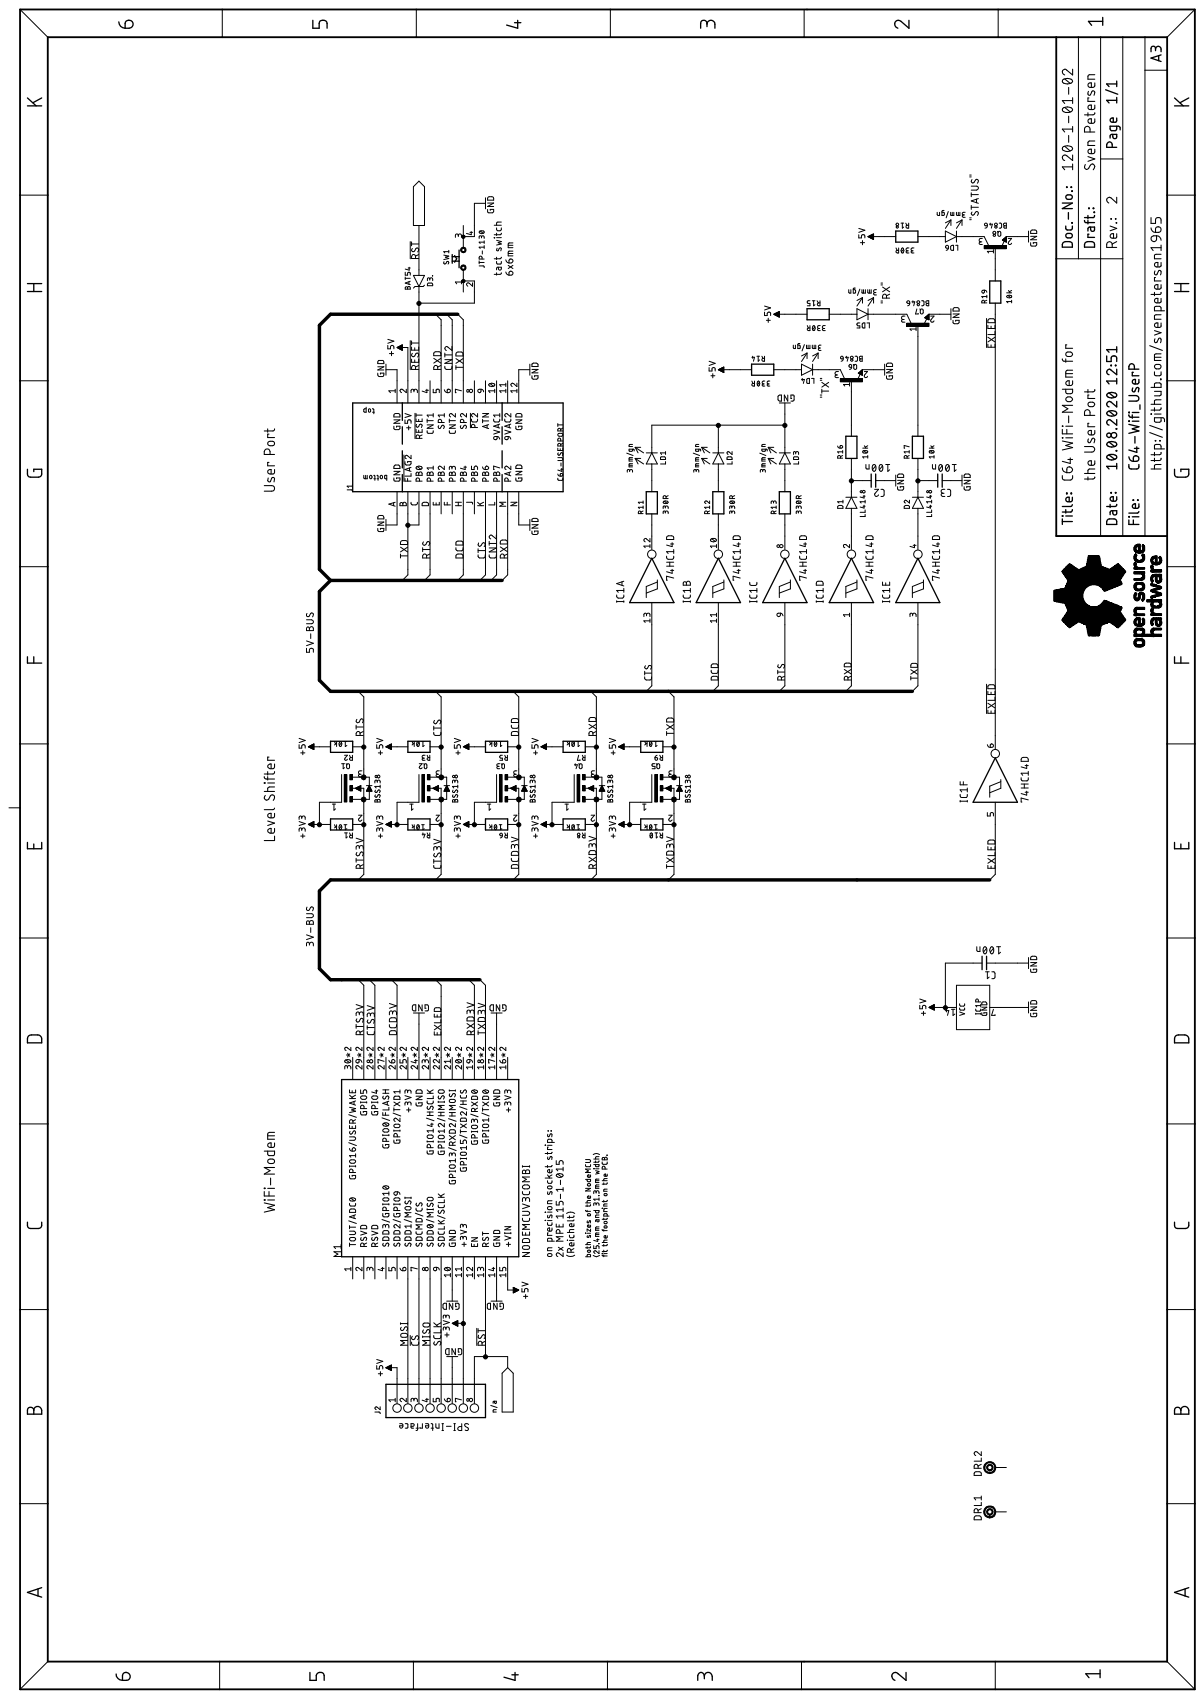
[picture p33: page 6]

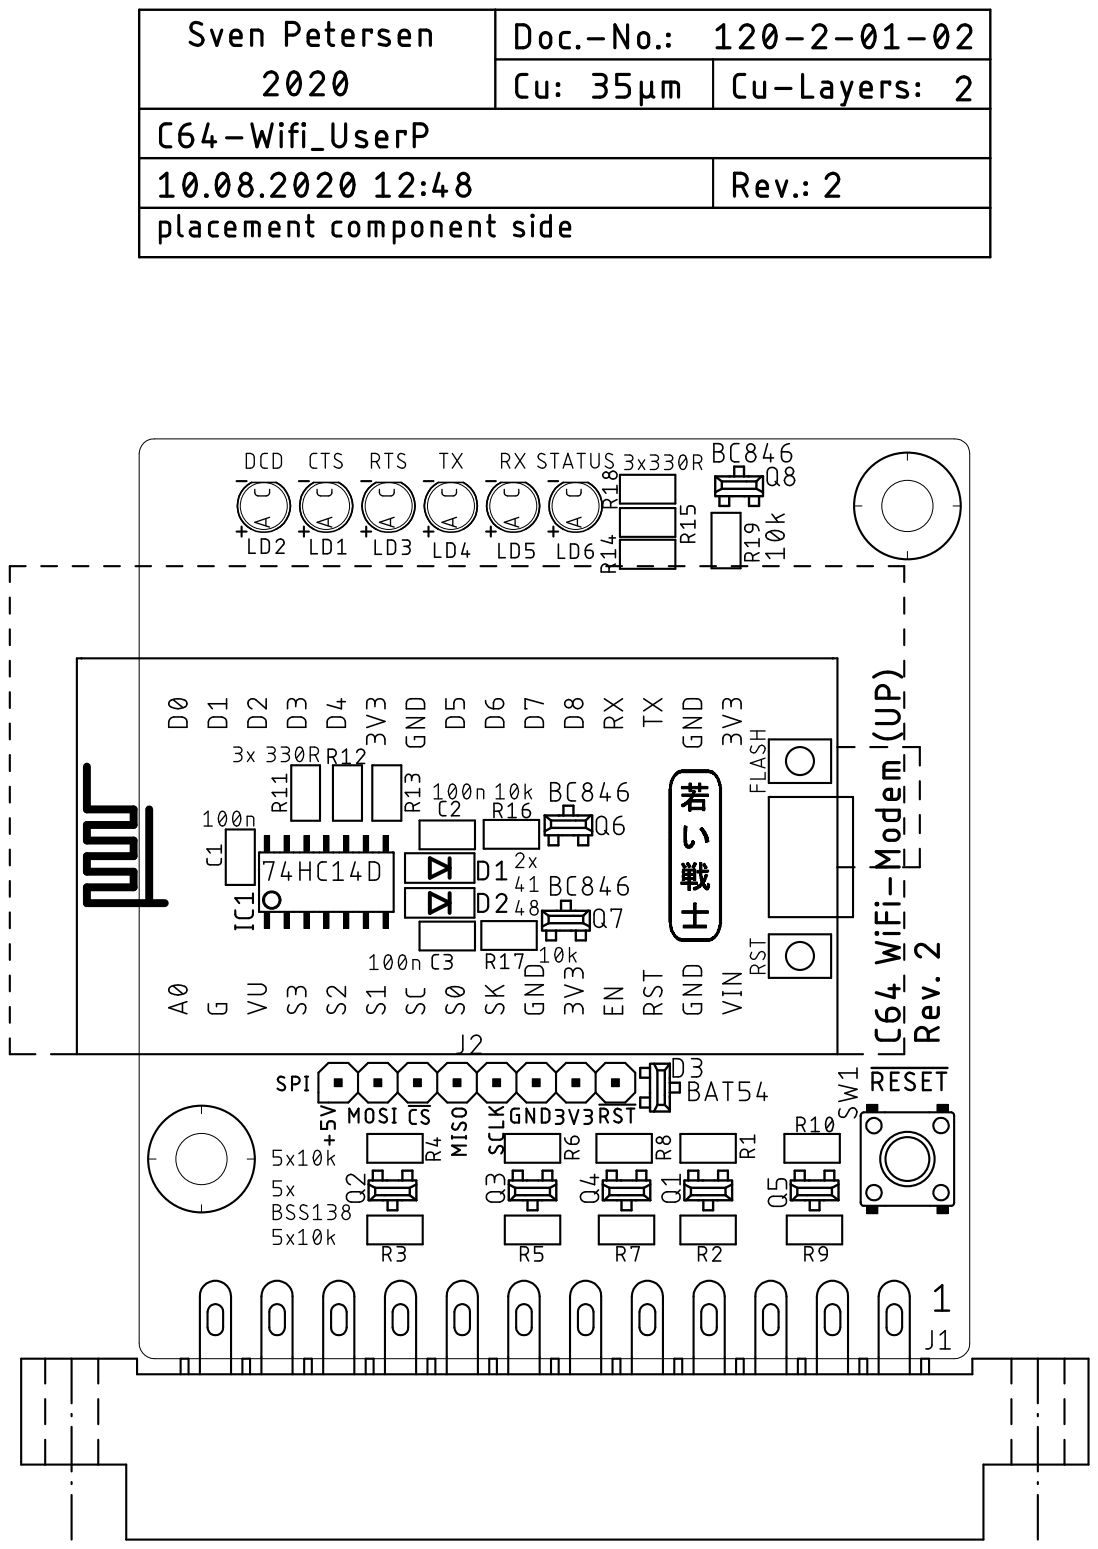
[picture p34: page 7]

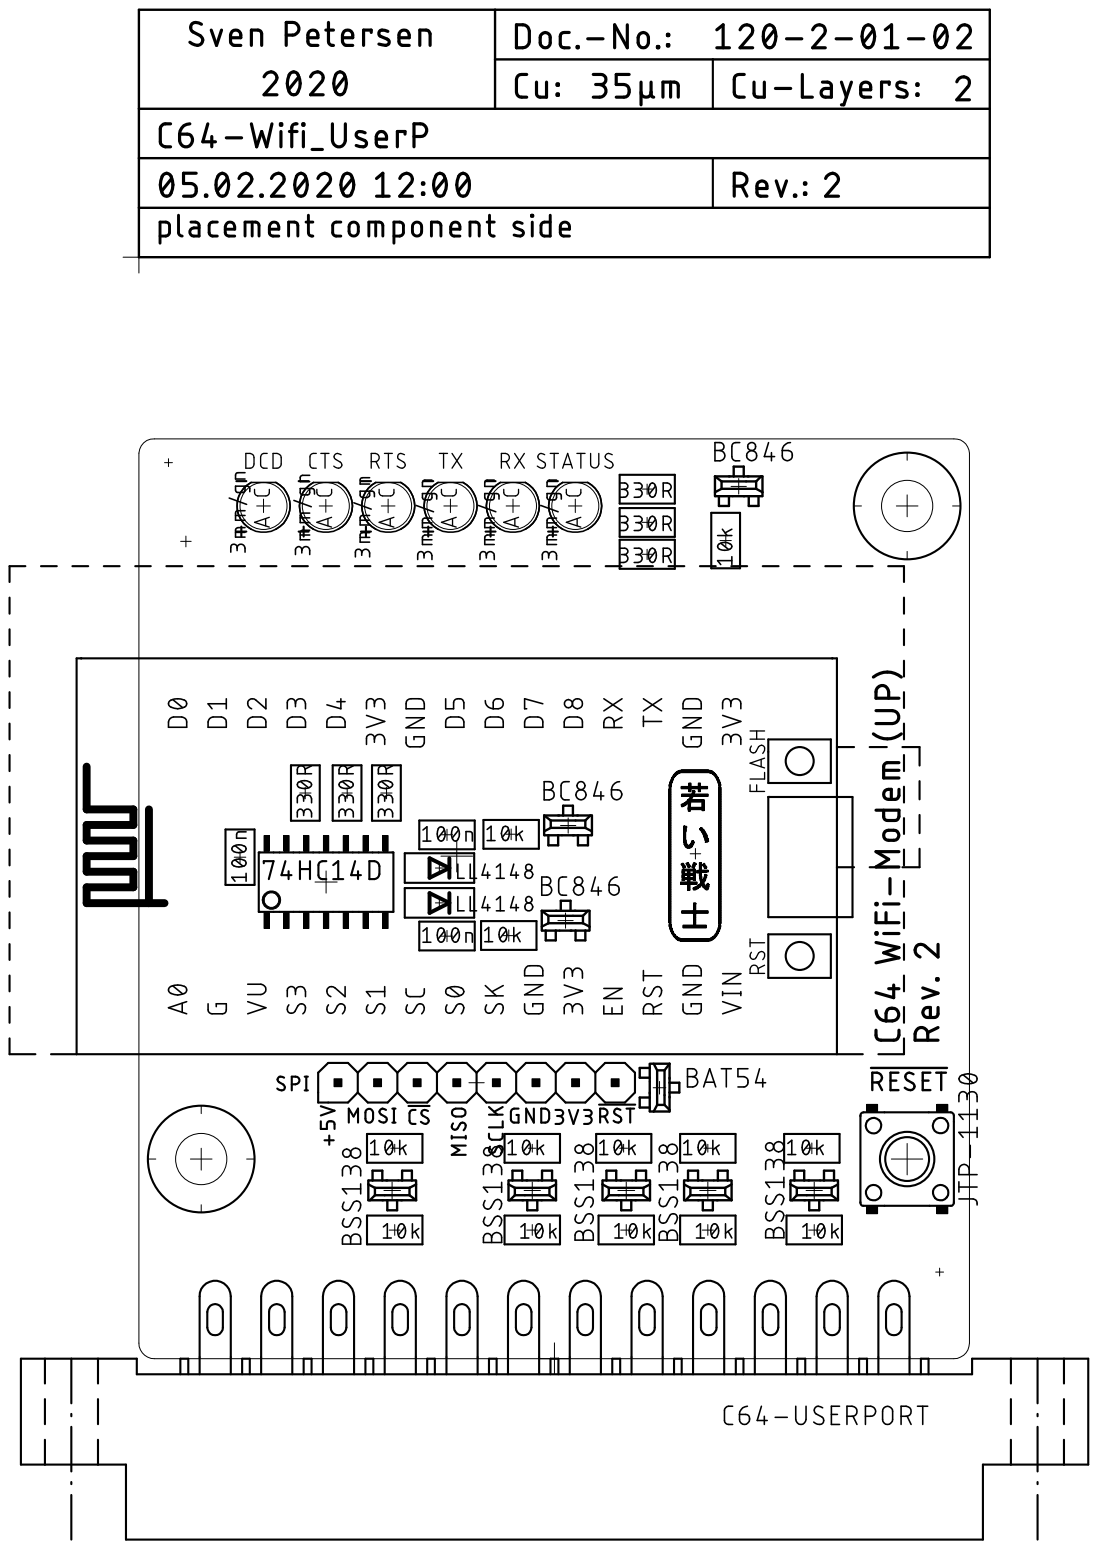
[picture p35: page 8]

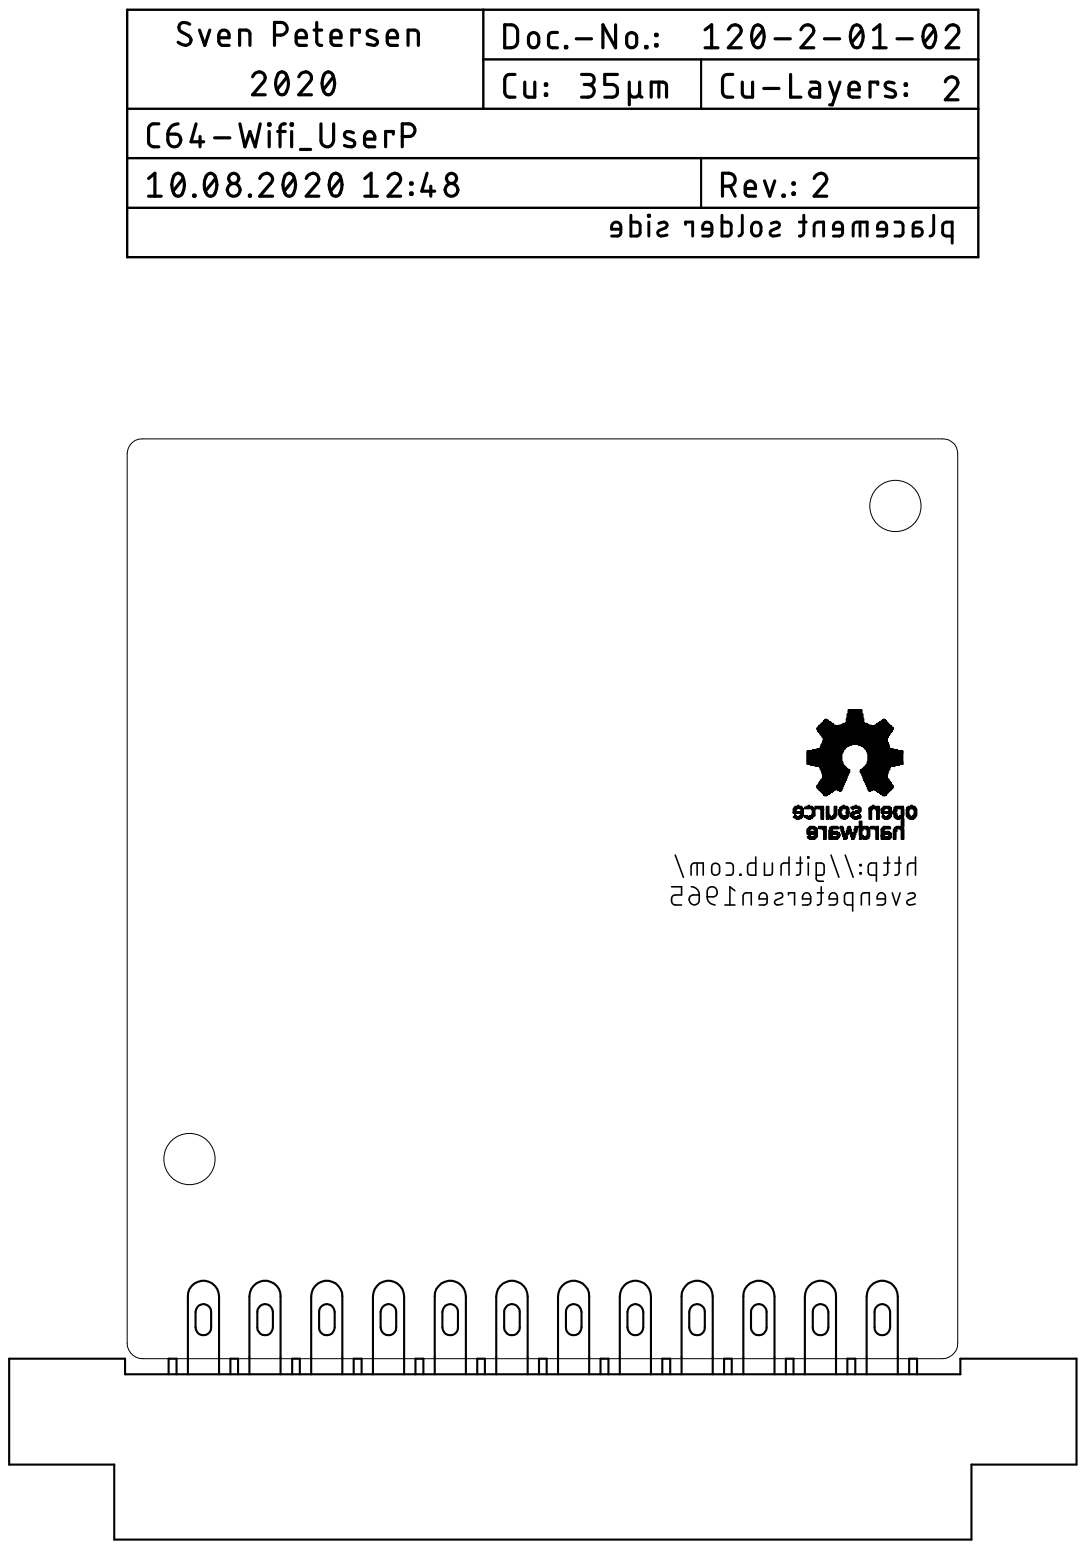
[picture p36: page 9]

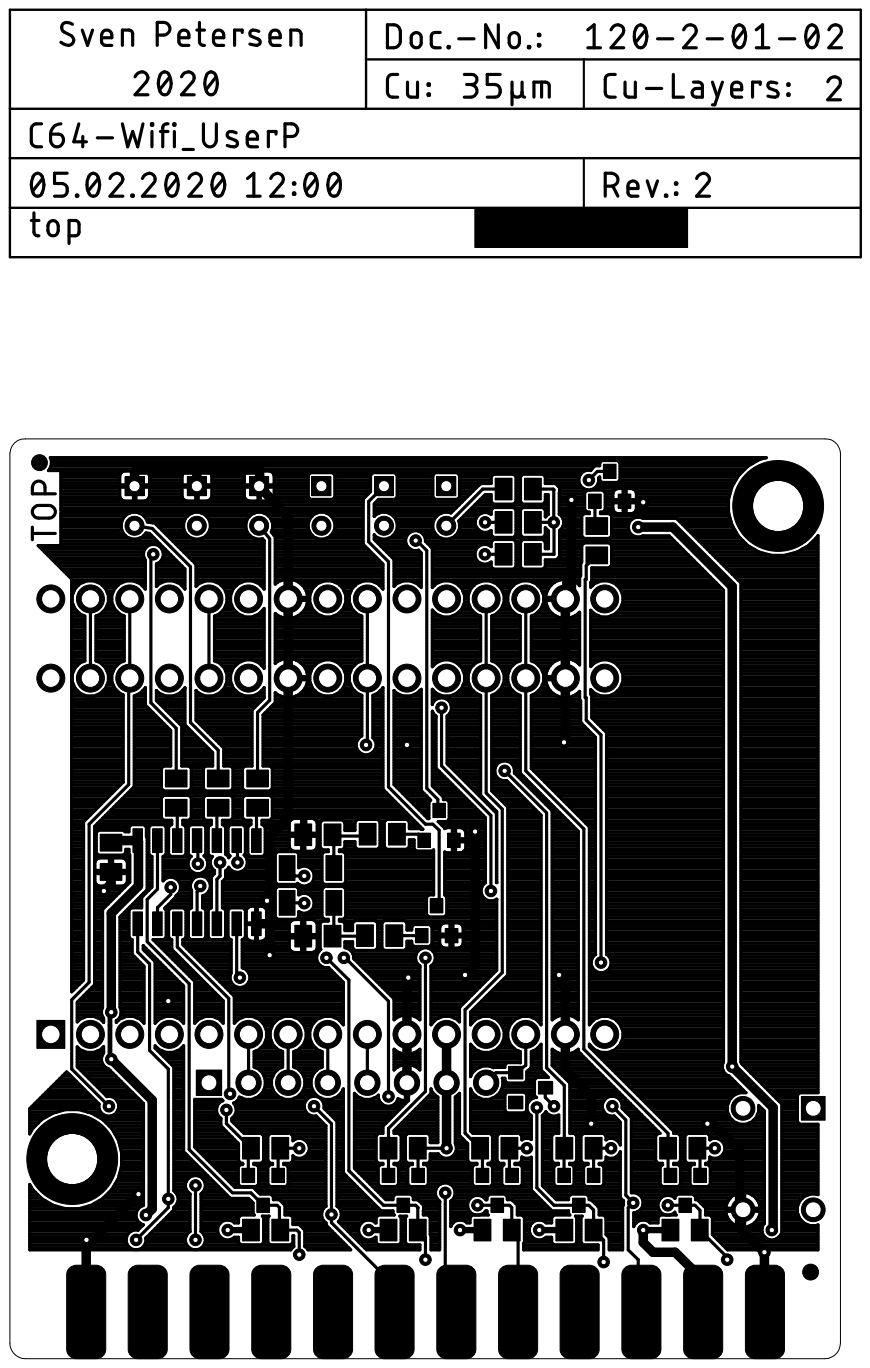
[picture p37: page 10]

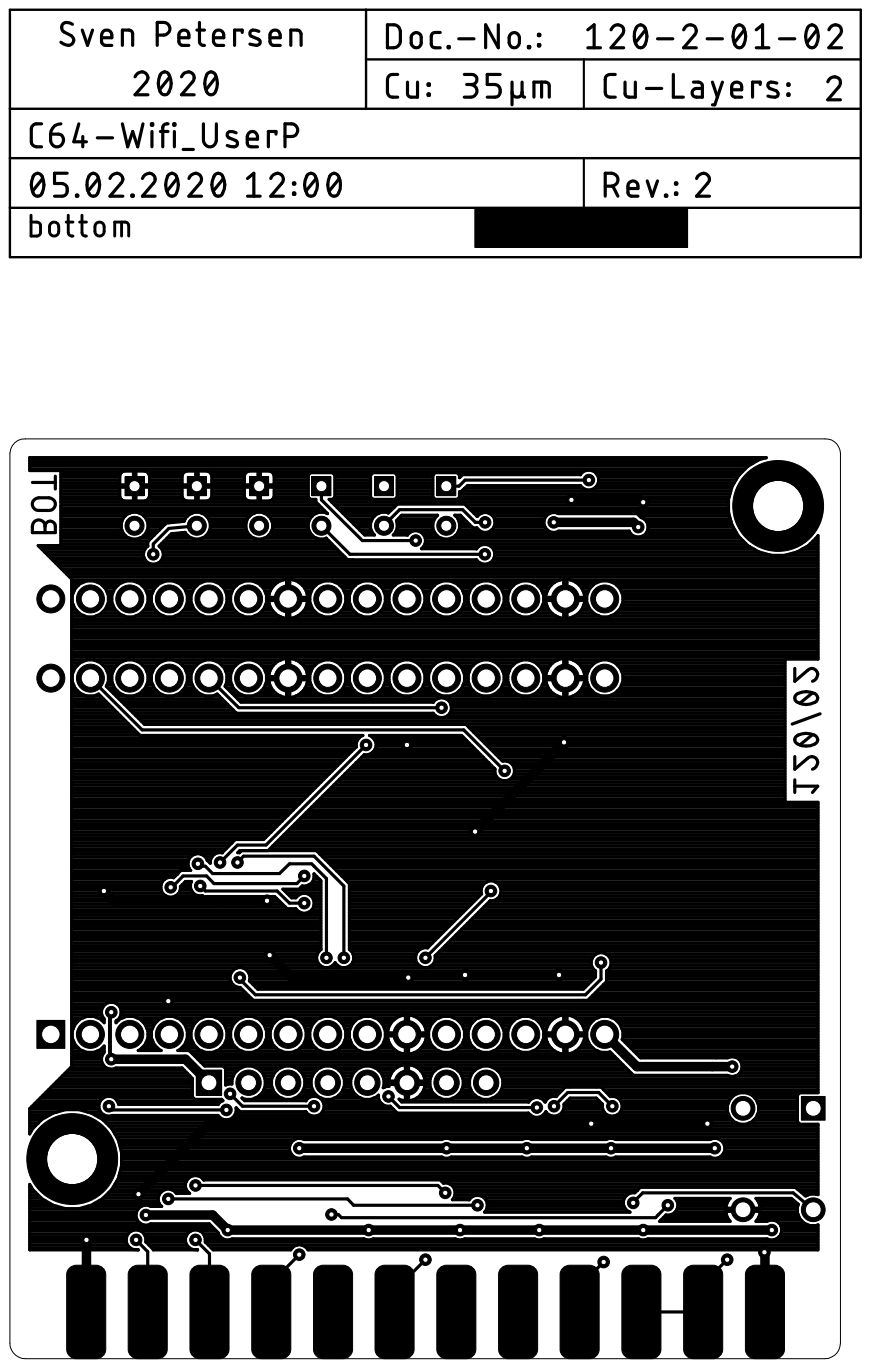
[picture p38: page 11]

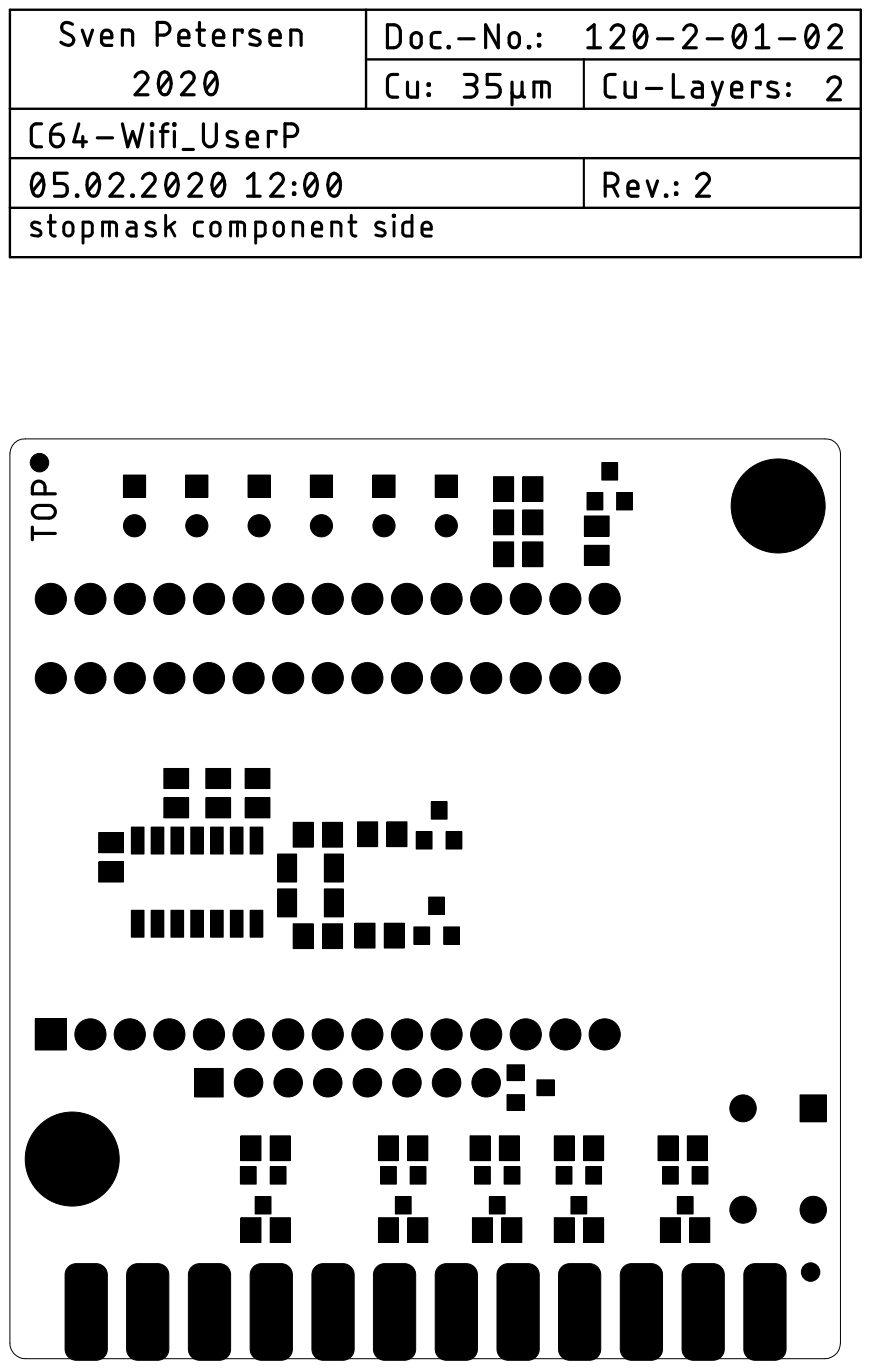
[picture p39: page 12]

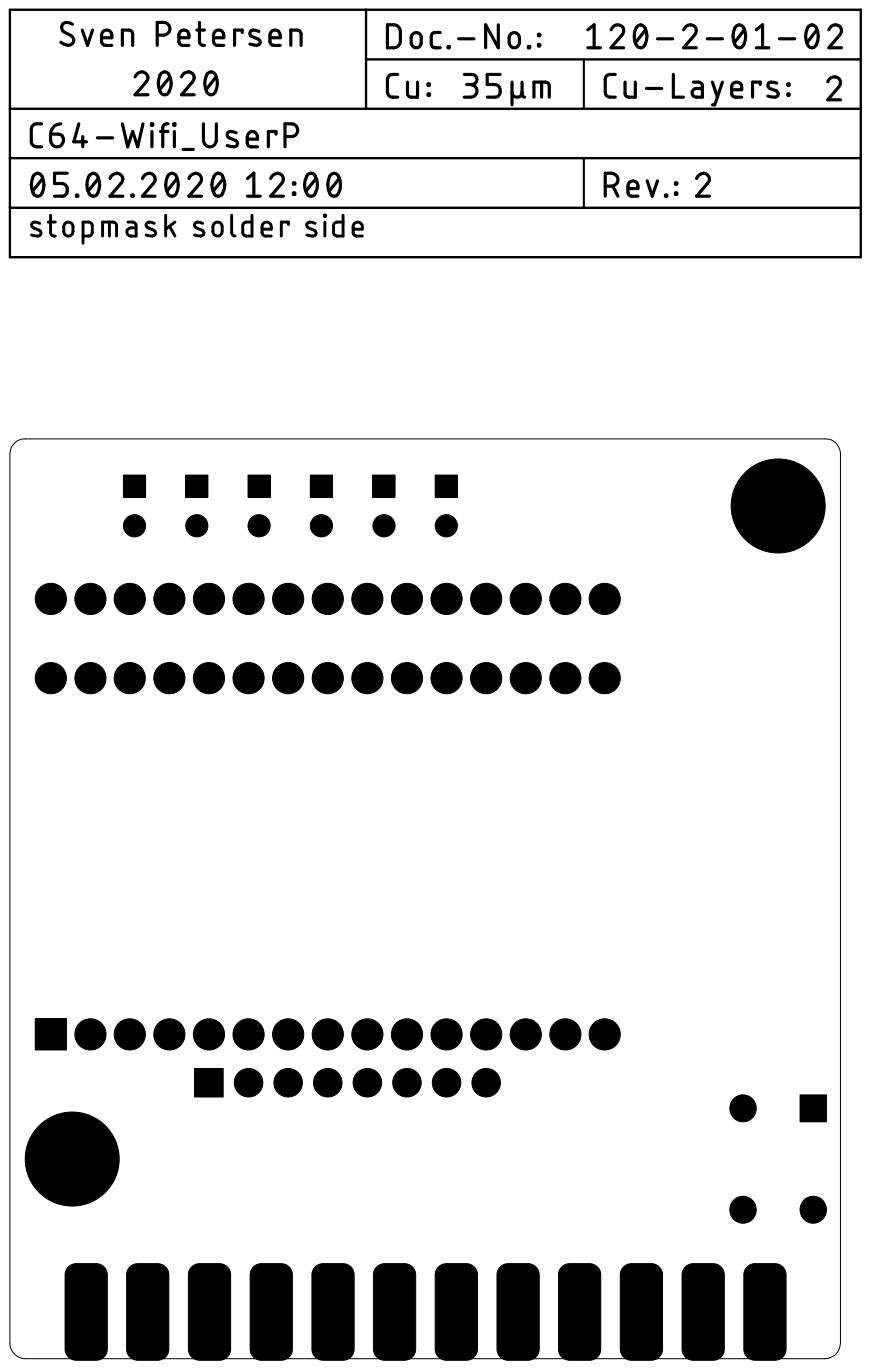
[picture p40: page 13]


C64-Wifi_UP_FunD.docx | | 05.02.2020 11:49
Drafted by Sven Petersen | Page 1 of 1 | Doc.-No.: 120-6-01-02

### C64 WiFi-Modem for User Port Rev. 2
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

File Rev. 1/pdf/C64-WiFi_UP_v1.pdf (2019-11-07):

# Project Documentation

## C64 WiFi-Modem for User Port

## Project number: 120

## Revision: 1

## Date: 17.07.2019


C64-Wifi_UP_ModD.docx | | 17.07.2019 18:07
Drafted by Sven Petersen | Page 1 of 3 | Doc.-No.: 120-6-01-01

### C64 WiFi-Modem for User Port Rev. 1

### Module Description

This board is a WiFi modem for the User Port of the Commodore C64. It is based on the project “Build your own 9600 Baud C64 WiFi Modem For $10” of “1200BAUD” (https://1200baud.wordpress.com/2017/03/04/build-your-own-9600-baud-c64-wifi-modem-for-20/). (https://1200baud.wordpress.com/2017/03/04/build-your-own-9600-baud-c64-wifi-modem-for-20/)

The WiFi functionality is implemented in the NODEMCU V3 development board/module, which contains an Espressive ESP8266, a WiFi and RISC processor. This module can be programmed with free software via a micro USB cable.

The board contains status and activity LEDs and connects to the User Port of the Commodore C64.

Figure 1: Dimensions of the WiFi modem board

For the NodeMCU V3 programming and the required C64 software, refer to the article mentioned before.

The board contains level shifters, that translate between the NodeMCU 3.3V level and the User Port 5V level. According to the data sheet, the ESP8266 is not 5V-level tolerant. Its protection diodes might limit the HIGH level to below 4V. Without the level shifters, the User Port/6526 CIA might be stressed by the HIGH level being pulled to this level.

C64-Wifi_UP_ModD.docx | | 17.07.2019 18:07
Drafted by Sven Petersen | Page 2 of 3 | Doc.-No.: 120-6-01-01

## Logic connections

| 3.3V level | | | 5V level
Pin | NodeMCU V3 | Signal | User Port | Pin
29 | GPIO5 (D1) | RTS | PB1 | D
28 | GPIO4 (D2) | CTS | PB6 | K
26 | GPIO2 (D4) | DCD | PB4 | H
22 | GPIO12 (D6) | Status-LED | - | -
19 | RXD0 (RX) | RXD | PA2, SP1 | M, 5
18 | TXD0 (TX) | TXD | /FLAG2, PB0, SP2 | B, C, 7
- | - | | PB7, CNT2 | L, 6

## Connectors

### User Port

### 2 x 12 edge connector, pitch 3.96mm

Pin Signal | Pin Signal
1 | GND | A | GBD
2 | +5V | B, C | TXD
3 | RESET | D | RTS
5 | RXD | H | DCD
6 | CNT2 | K | CTS
7 | TXD | L | CNT2
12 | GND | M | RXD
| | N GND

### SPI (spare)

8p. pin header, pitch 2.54mm. The function of the SPI-Bus is not implemented in the NodeMCU software. The signals have a 3.3V level. 3.3V, 5V and GND are connected to this pin header.

Pin Signal
1 +5V
2 MOSI
3 CS

4 MISO
5 SCLK
6 GND
7 +3.3V
8 RST (Reset Signal NodeMCU)

## Revision History

### Rev. 0

Prototype, functional. Labeling of the LEDs was not perfect, the Status LED was inverted.

C64-Wifi_UP_ModD.docx | | 17.07.2019 18:07
Drafted by Sven Petersen | Page 3 of 3 | Doc.-No.: 120-6-01-01

### Rev. 0 → Rev. 1

- Board Revision
- LEDs changed to 3mm standard LEDs
- The “WiFi” LED is now named “Status” and it is inverted
- The Labeling from RX and TX was swapped, since before it was labeled from the perspective of the NodeMCU
- Positions of LEDs have moved
- A pin header for a spare SPI-Bus connection is added
- Two mounting holes for a not yet designed enclosure are added
- A RESET -Button is added
- The C64 Reset affects the NodeMCU









C64-Wifi_UP_FunD.docx | | 17.07.2019 18:16
Drafted by Sven Petersen | Page 1 of 1 | Doc.-No.: 120-6-01-01

### C64 WiFi-Modem for User Port Rev. 1
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

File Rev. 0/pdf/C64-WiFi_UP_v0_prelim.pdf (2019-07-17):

# Project Documentation

## C64 WiFi-Modem for User Port

## Project number: 120

## Revision: 0

## Date: 29.03.2019


C64-Wifi_UP_ModD.docx | | 24.05.2019 21:26
Drafted by Sven Petersen | Page 1 of 2 | Doc.-No.: 120-6-01-00

### C64 WiFi-Modem for User Port Rev. 0

### Module Description

This board is a WiFi modem for the User Port of the Commodore C64. It is based on the project “Build your own 9600 Baud C64 WiFi Modem For $10” of “1200BAUD” (https://1200baud.wordpress.com/2017/03/04/build-your-own-9600-baud-c64-wifi-modem-for-20/). (https://1200baud.wordpress.com/2017/03/04/build-your-own-9600-baud-c64-wifi-modem-for-20/)

The WiFi functionality is implemented in the NODEMCU V3 development board/module, which contains an Espressive ESP8266 WiFi and RISC processor. This module can be programmed with free software via a micro USB cable.

The board contains status and activity LEDs and connects to the User Port of the Commodore C64.

Figure 1: Dimensions of the WiFi modem board

For the NodeMCU V3 programming and the required C64 software, refer to the article mentioned above.

## Logic connections

| 3.3V level | | | 5V level
Pin | NodeMCU V3 | Signal | User Port | Pin
29 | GPIO5 (D1) | RTS | PB1 | D
28 | GPIO4 (D2) | CTS | PB6 | K
26 | GPIO2 (D4) | DCD | PB4 | H

C64-Wifi_UP_ModD.docx | | 24.05.2019 21:26
Drafted by Sven Petersen | Page 2 of 2 | Doc.-No.: 120-6-01-00
| 3.3V level | | | 5V level
Pin | NodeMCU V3 | Signal | User Port | Pin
22 | GPIO12 (D6) | WiFi-LED* | - | -
19 | RXD0 (RX) | RXD | PA2, SP1 | M, 5
18 | TXD0 (TX) | TXD | /FLAG2, PB0, SP2 | B, C, 7
- | - | | PB7, CNT2 | L, 6

*The function of the WiFi-LED is not implemented in the original software.









C64-Wifi_UP_FunD.docx | | 24.05.2019 21:27
Drafted by Sven Petersen | Page 1 of 1 | Doc.-No.: 120-6-01-00

### C64 WiFi-Modem for User Port Rev. 0

### Functional Description

J1 is connecting to the C64 user port. The logic levels are TTL (5V)-levels. The NodeMCU v3 (M1) contains all functionality, WiFi included. Its signal level is 3.3V, so level shifters are required. Those are implemented in the MOSFETs (Q1 – Q5).

The modem signals are active low. The inverters (IC1) are used to drive LEDs. The RxD and TxD lines might toggle often. To obtain a good LED brightness, the output of the inverters IC1D and IC1E are buffered in a capacitor, which is charged via a diode and discharged via the base resistor and the base of a transistor, which is then driving an LED.

The last LED (LD6) is driven by the signal EXLED from the NodeMCU. It can serve as a status

### LED (e.g. for WiFi), which needs to be implemented in the NodeMCU’s software, otherwise

the behavior of the LED is not defined.

C64-Wifi_UP_Testing_v0.docx | | 17.07.2019 19:04
Drafted by Sven Petersen | Page 1 of 1 | Doc.-No.: 120-6-03-00

### C64 WIFI Modem (User Port) Rev. 0

### Testing

## Setup

The C64 WiFi Modem Rev. 0 is driven by a C64 (Mainboard: ASSY250469 with ARMSID), which also connects to an Ultimate II+. The NodeMCU’s firmware was installed and running.

## Current consumption

The current is measured with a Fluke 89 IV multimeter, which is connected between the power supply and the Power jack of the C64.

First the maximum current of the C64 setup mentioned before is determined without the DUT being connected to the user port. CCGMS 2017 v6 was loaded from the Ultimate II+.

The measured result IMAX is 998.7mA.

In the next step, the DUT was connected and the measurement was repeated. This time, the result is 1095.5mA.

The current consumption of the Modem board might vary depending on the operations/state. It can eb assumed, that is it approximately 100mA.
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

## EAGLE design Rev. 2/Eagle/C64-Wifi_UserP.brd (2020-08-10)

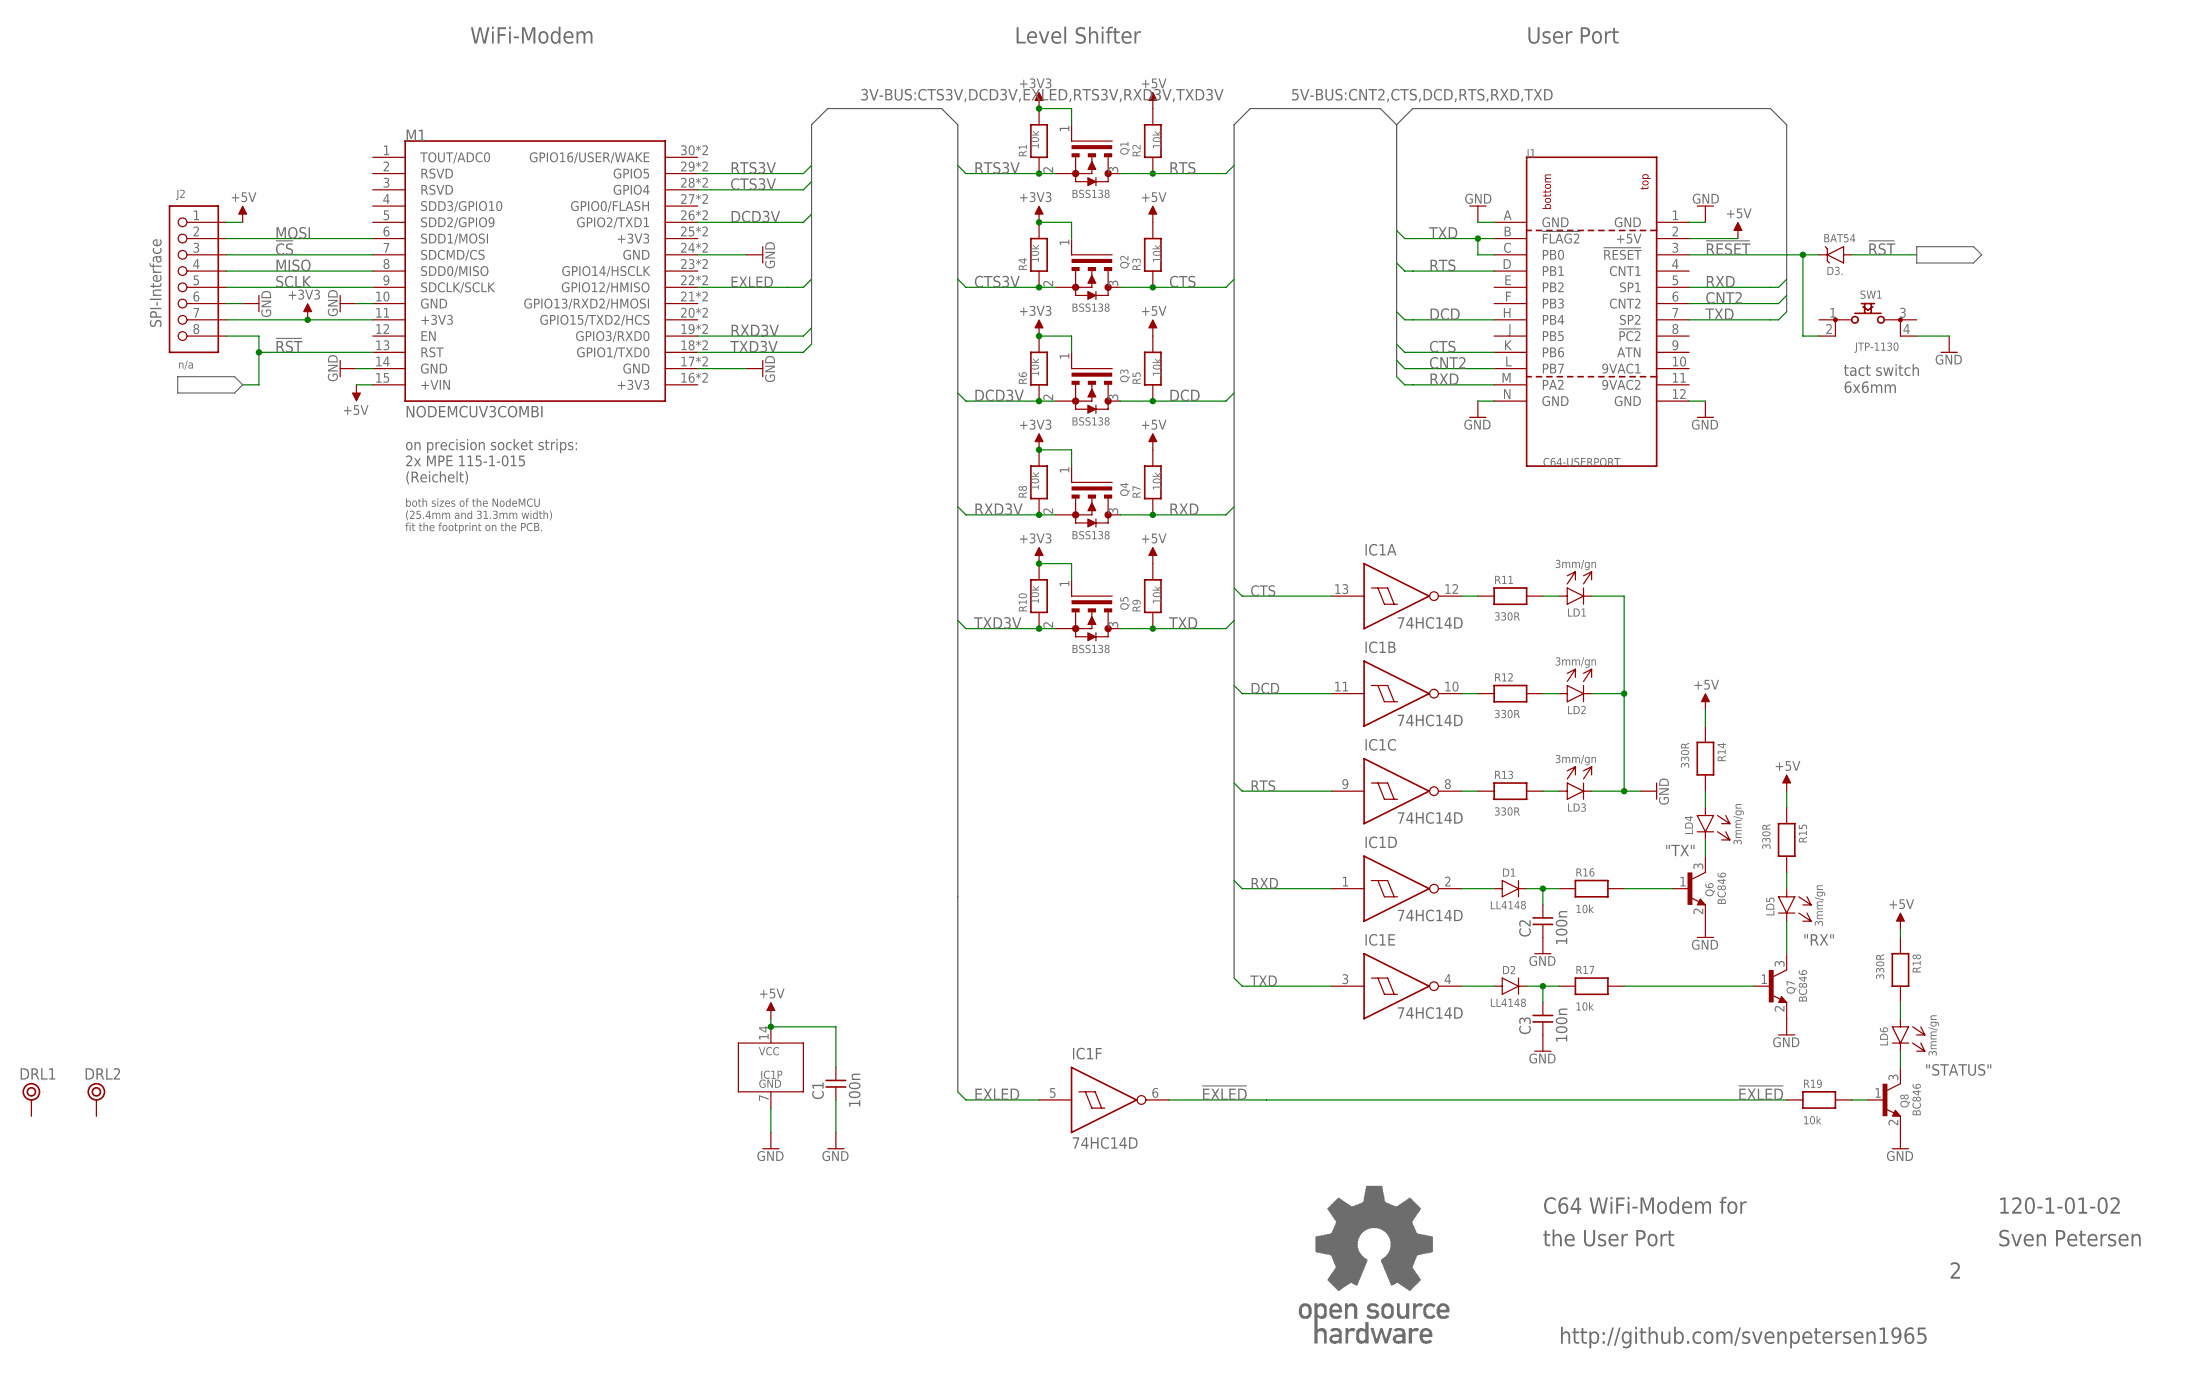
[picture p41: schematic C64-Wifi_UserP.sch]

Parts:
C1, C2, C3: 100n; 0805
D1, D2: LL4148; SOD80C
D3: BAT54; SOT23
DRL1, DRL2: BOHR3,3
IC1: 74HC14D; SO-14
J1: C64-USERPORT; USERPORT
J2: n/a; 1X08
LD1, LD2, LD3, LD4, LD5, LD6: 3mm/gn; 3MM
M1: NODEMCUV3COMBI; NODEMCUV3_X
Q1, Q2, Q3, Q4, Q5: BSS138; SOT23
Q6, Q7, Q8: BC846; SOT23
R1, R2, R3, R4, R5, R6, R7, R8, R9, R10, R16, R17, R19: 10k; 0805
R11, R12, R13, R14, R15, R18: 330R; 0805
SW1: JTP-1130
U$45: OPEN_SOURCE_HW; OPENHW

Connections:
9VAC1: J1.10 (9VAC1)
9VAC2: J1.11 (9VAC2)
!CS: J2.3, M1.7 (SDCMD/CS)
!EXLED: IC1.6 (O), R19.1
!RESET: D3.3 (K), J1.3 (!RESET), SW1.2
!RST: D3.1 (A), J2.8, M1.13 (RST)
+3V3: J2.7, M1.11 (+3V3), Q1.1 (G), Q2.1 (G), Q3.1 (G), Q4.1 (G), Q5.1 (G), R1.2, R4.2, R6.2, R8.2, R10.2
+5V: C1.2, IC1.14 (VCC), J1.2 (+5V), J2.1, M1.15 (+VIN), R2.2, R3.2, R5.2, R7.2, R9.2, R14.1, R15.1, R18.1
CNT2: J1.6 (CNT2), J1.L (PB7)
CTS: IC1.13 (I), J1.K (PB6), Q2.3 (D), R3.1
CTS3V: M1.28 (GPIO4), M1.28W (GPIO4), Q2.2 (S), R4.1
DCD: IC1.11 (I), J1.H (PB4), Q3.3 (D), R5.1
DCD3V: M1.26 (GPIO2/TXD1), M1.26W (GPIO2/TXD1), Q3.2 (S), R6.1
EXLED: IC1.5 (I), M1.22 (GPIO12/HMISO), M1.22W (GPIO12/HMISO)
GND: C1.1, C2.1, C3.1, IC1.7 (GND), J1.1 (GND), J1.12 (GND), J1.A (GND), J1.N (GND), J2.6, LD1.C (K), LD2.C (K), LD3.C (K), M1.10 (GND), M1.14 (GND), M1.17 (GND), M1.17W (GND), M1.24 (GND), M1.24W (GND), Q6.2 (E), Q7.2 (E), Q8.2 (E), SW1.4
MISO: J2.4, M1.8 (SDD0/MISO)
MOSI: J2.2, M1.6 (SDD1/MOSI)
unnamed: IC1.12 (O), R11.1
unnamed: IC1.10 (O), R12.1
unnamed: IC1.8 (O), R13.1
unnamed: D1.A, IC1.2 (O)
unnamed: D2.A, IC1.4 (O)
unnamed: LD5.A, R15.2
unnamed: LD4.A, R14.2
unnamed: LD3.A, R13.2
unnamed: LD2.A, R12.2
unnamed: LD1.A, R11.2
unnamed: C2.2, D1.K, R16.1
unnamed: C3.2, D2.K, R17.1
unnamed: Q6.1 (B), R16.2
unnamed: Q7.1 (B), R17.2
unnamed: LD4.C (K), Q6.3 (C)
unnamed: LD5.C (K), Q7.3 (C)
unnamed: LD6.A, R18.2
unnamed: LD6.C (K), Q8.3 (C)
unnamed: Q8.1 (B), R19.2
RTS: IC1.9 (I), J1.D (PB1), Q1.3 (D), R2.1
RTS3V: M1.29 (GPIO5), M1.29W (GPIO5), Q1.2 (S), R1.1
RXD: IC1.1 (I), J1.5 (SP1), J1.M (PA2), Q4.3 (D), R7.1
RXD3V: M1.19 (GPIO3/RXD0), M1.19W (GPIO3/RXD0), Q4.2 (S), R8.1
SCLK: J2.5, M1.9 (SDCLK/SCLK)
TXD: IC1.3 (I), J1.7 (SP2), J1.B (!FLAG2), J1.C (PB0), Q5.3 (D), R9.1
TXD3V: M1.18 (GPIO1/TXD0), M1.18W (GPIO1/TXD0), Q5.2 (S), R10.1

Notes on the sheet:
WiFi-Modem
Level Shifter
User Port
C64 WiFi-Modem for
the User Port
120-1-01-02
Sven Petersen
on precision socket strips: 2x MPE 115-1-015 (Reichelt)
"TX"
"RX"
"STATUS"
SPI-Interface
both sizes of the NodeMCU (25.4mm and 31.3mm width) fit the footprint on the PCB.
http://github.com/svenpetersen1965
tact switch 6x6mm

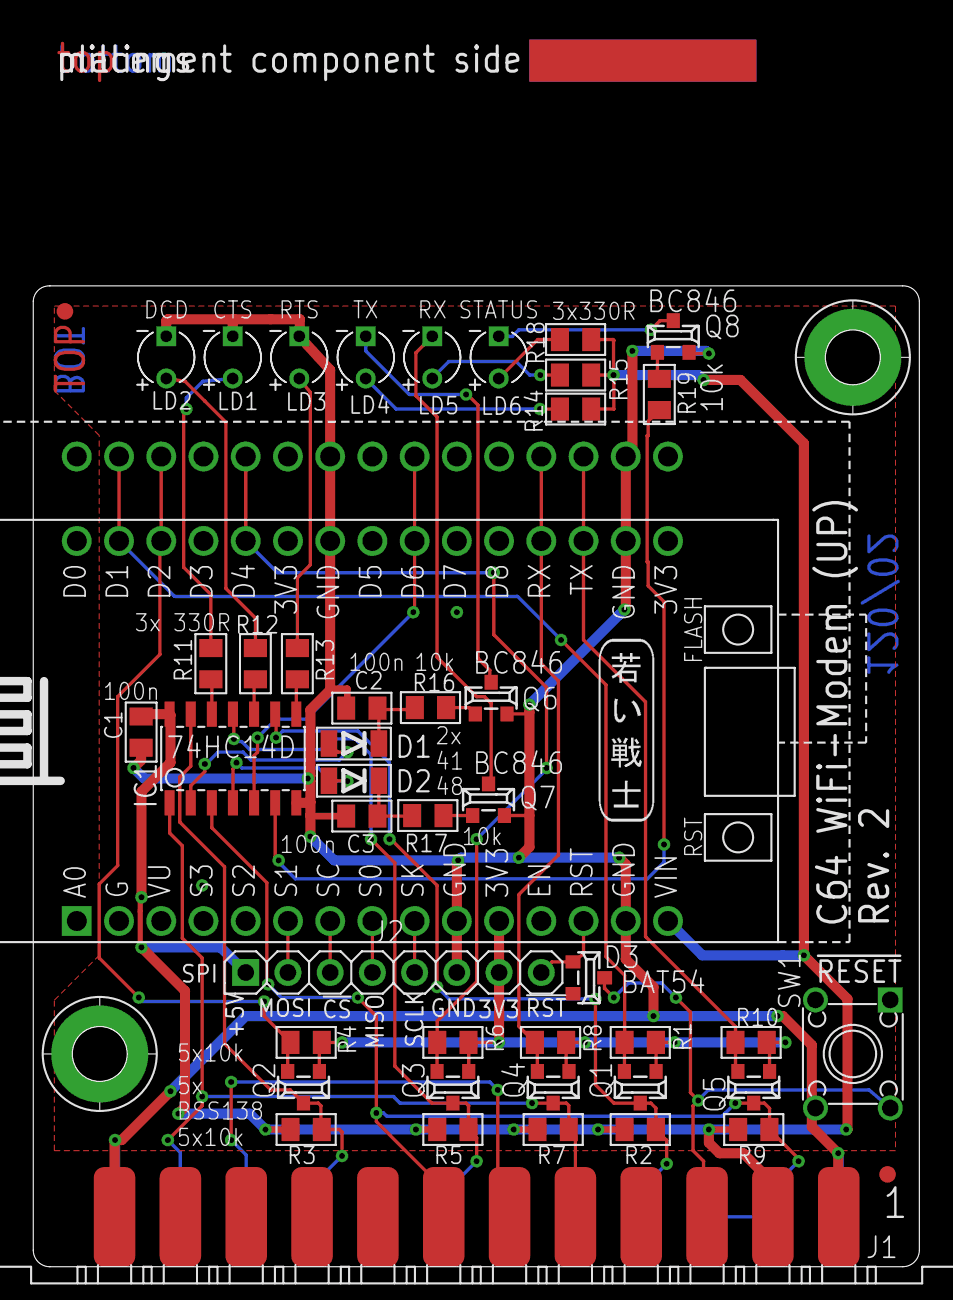
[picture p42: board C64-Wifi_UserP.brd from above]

Board: 2 copper layers, 53.3 x 59.0 mm, 52 parts (1 on the bottom side), 41 nets.

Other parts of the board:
U$36: PCB-TITLE/
U$37: 2LAYER
U$38, U$39: SMD_REF_R1MM
U$44: SVEN_TAG

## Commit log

2019-10-15 Case added for the revision 0 or the PCB
    [Top shell.stl, bottom shell.stl]
2020-03-20 Case for PCB Rev. 2 released, rearranged directories
    [C64-WiFi_UP_PCB2 v9.f3d, C64-Wifi_UP_PCB0 v6.f3d, C64-Wifi_UserP v34.f3d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]
2020-03-20 Rev. 2 released
    [C64-WiFi_UP_BOM_v2_0.xlsx, C64-Wifi_UserP.brd, C64-Wifi_UserP.dxf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]
2020-06-09 Calculation of the component prices
    A calculation of the component prices was added (June 8th, 2020)
    [C64-WiFi_UP_BOM_v2_0_calc.xlsx]
2020-08-10 Silk Screen Update
    [C64-Wifi_UserP.brd, C64-Wifi_UserP.sch]
2022-02-26 Gerbers removed
2026-05-02 Gerbers without document frame
